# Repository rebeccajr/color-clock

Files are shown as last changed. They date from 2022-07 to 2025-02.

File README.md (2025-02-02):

# ColorClock

## Code Location

The code base is contained in the Arduino directory located at
[./sw/arduino/color-clock-driver](./sw/arduino/color-clock-driver).

## Hardware

The project was designed using an `MKR1010` Arduino board that
interfaces with a real time clock module to keep accurate time.

### Wiring Diagram

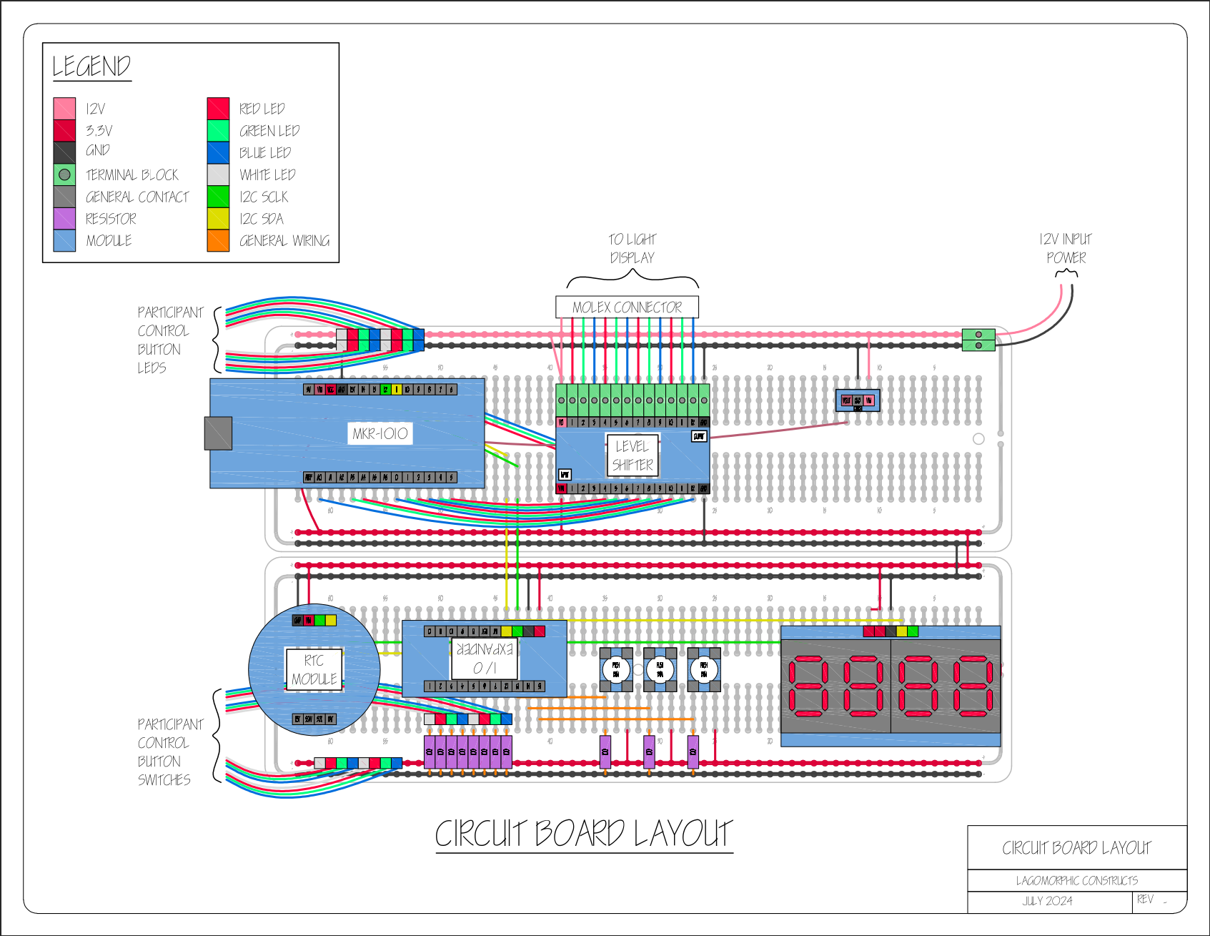
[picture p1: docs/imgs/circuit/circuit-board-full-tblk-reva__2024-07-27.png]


## Documentation

The blog about this project can be found
[here](http://rebeccarashkin.com/color-clock).

A slide deck that contains an overview of the project can be found
[here](./docs/slide-decks/2024-08-10__demo/_color-clock-demo__2024-08-10.pdf)

## Description

Version 1 of ColorClock was an art piece displayed at Burning Man in
2024. The piece was a minimalist lean-to shade structure, housing a
2.5 ft diameter light display at its core. Within, a bench invited
participants to rest just above the playa. The light display, crafted
with concentric circles, marked the current time, providing nuanced
granularity such as the hour and minute. A user-controllable central
light introduced an element of interactivity. With a control panel,
the participant could manage cycle time and spectrum hues, enhancing the
understanding of the piece. ColorClock, in its simplicity and
interactivity, prompts contemplation on the temporal interplay of light
against the expansive backdrop of the playa landscape.

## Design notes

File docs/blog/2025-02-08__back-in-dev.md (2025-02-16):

# Back In Development

I would like to make the ColorClock code base more robust, so I
decided to leverage some of the work I'm doing in my real job and
applying it to ColorClock.

## Google Test

During development of ColorClock Version 1, I did some rudimentary
unit tests that took the form of print statements in simple C++
programs. I played around with writing makefiles but my unit tests were
few and far between.

In my latest work, I'm implementing a "real" unit testing framework in
using Google Test. Each module has its own test file and I'm using
**make** to build the unit test executable.

## Testing Limitations

Since ColorClock is designed to work with specific hardware, some of the
code isn’t easily testable using Google Test. However, much (or at least
some) of the hardware-dependent functionality is protected by
preprocessor directives, providing alternate behavior for non-hardware
builds. My goal is to write unit tests for as many functions as
possible.

## This Is Why We Test

So, I’ve started writing tests for the edge cases in the TimeCalcs
module, and guess what? I found some errors in one of the functions 😅

I didn't run into these issues with ColorClock Version 1 because it was
built for a specific use case, but as I expand the project, I need to
address them 😬

*Google Test Output for TimeCalcs*

```googletest
[==========] Running 5 tests from 1 test suite.
[----------] Global test environment set-up.
[----------] 5 tests from TimeCalcsGroup
[ RUN      ] TimeCalcsGroup.TimeAsFractionalOffset_Nominal
[       OK ] TimeCalcsGroup.TimeAsFractionalOffset_Nominal (0 ms)
[ RUN      ] TimeCalcsGroup.TimeAsFractionalOffset_Nominal_Swapped
[       OK ] TimeCalcsGroup.TimeAsFractionalOffset_Nominal_Swapped (0 ms)
[ RUN      ] TimeCalcsGroup.TimeAsFractionalOffset_Across_Midnight
/home/flux/git/color-clock/sw/test/build-test/../main/test-time-calcs.cpp:69: Failure
Value of: function_output == 0.75
  Actual: false
Expected: true

[  FAILED  ] TimeCalcsGroup.TimeAsFractionalOffset_Across_Midnight (0 ms)
[ RUN      ] TimeCalcsGroup.TimeAsFractionalOffset_Midnight_As_24_End
[       OK ] TimeCalcsGroup.TimeAsFractionalOffset_Midnight_As_24_End (0 ms)
[ RUN      ] TimeCalcsGroup.TimeAsFractionalOffset_Midnight_As_0_End
/home/flux/git/color-clock/sw/test/build-test/../main/test-time-calcs.cpp:95: Failure
Value of: function_output == 0.5
  Actual: false
Expected: true

[  FAILED  ] TimeCalcsGroup.TimeAsFractionalOffset_Midnight_As_0_End (0 ms)
[----------] 5 tests from TimeCalcsGroup (0 ms total)

[----------] Global test environment tear-down
[==========] 5 tests from 1 test suite ran. (0 ms total)
[  PASSED  ] 3 tests.
[  FAILED  ] 2 tests, listed below:
[  FAILED  ] TimeCalcsGroup.TimeAsFractionalOffset_Across_Midnight
[  FAILED  ] TimeCalcsGroup.TimeAsFractionalOffset_Midnight_As_0_End

 2 FAILED TESTS
```

## Build Flags

I have a file called [flux_macros.hpp](https://github.com/rebeccajr/color-clock/blob/main/sw/arduino/color-clock-driver/flux-macros.hpp)
that defines all the build flags, including preprocessor directives for
enabling hardware-specific functionality. This file is included in every
software module. One of its macros, **DEBUG_CPP**, is meant for
non-hardware builds. Until now, I’ve had to manually set this flag in
the macros file. To streamline the process, I wrote a simple
[Python script](https://github.com/rebeccajr/color-clock/blob/main/sw/test/build-test/add-debug-macros.py) that automatically uncomments the line.

```cpp
// #define DEBUG_CPP
```

and converts it to:

```cpp
#define DEBUG_CPP
```

In the [makefile](https://github.com/rebeccajr/color-clock/blob/main/sw/test/build-test/Makefile)
for the unit tests, I create a phony target that runs the Python script
first before building out the unit test executable 😎

## File Headers

Another improvement I made to give the code a more professional look was
adding a comment header to each file. To make this process more
efficient, I wrote a Python script that automatically populates the
header in each file.

```cpp
//__________________________________________________________________
//__________________________________________________________________
//      _   __   _   _ _   _   _   _         _
// |   |_| | _  | | | V | | | | / |_/ |_| | /
// |__ | | |__| |_| |   | |_| | \ |   | | | \_
//  _  _         _ ___  _       _ ___   _                   / /
// /  | | |\ |  \   |  | / | | /   |   \                   (^^)
// \_ |_| | \| _/   |  | \ |_| \_  |  _/                   (____)o
//_________________________________________________________________
//_________________________________________________________________
//
//-----------------------------------------------------------------
// Copyright 2024, Rebecca Rashkin
// -------------------------------
// This code may be copied, redistributed, transformed, or built
// upon in any format for educational, non-commercial purposes.
//
// Please give me appropriate credit should you choose to use this
// resource. Thank you :)
//-----------------------------------------------------------------
//
//_________________________________________________________________
// //\^.^/\\   //\^.^/\\   //\^.^/\\   //\^.^/\\   //\^.^/\\   //\^
//_________________________________________________________________
```

*We named our artist collective (currently me, Bo, and our friend Cody)
'Lagomorphic Constructs.' Lagomorpha is the taxonomic order that
includes rabbits—and I love rabbits. So, naturally, I went with
'Lagomorphic Constructs' 🐰*

## Home Display

On a different note, we are also working on installing the light display
for ColorClock Version 1 in the house 🏠

I powered it up for the first time since its display at Burning Man
2024 and was thrilled to see that not only did it work, but
the time was still accurate thanks to the 'real-time clock module 🎉

The first step to converting it to a home display is to sort out the
wiring...

*For ColorClock Version 1, the light display's wiring was terminated
with a Molex connector, which connected to a wire harness. The harness
then led to a 12-way terminal block mounted on the structure, which
interfaced with the electronics box.*

The diagram above was generated using DOT, a scripting language for
creating vector images. It's another technology I use at work and have
recently started incorporating into ColorClock.

*For home display, we removed the wire harness from Version 1 and directly connected the LED strips to the terminal block, which we relocated to the back of the light display.*

## TODO

Moving forward, I have a few tasks on my to-do list that I’ll continue
chipping away at...

### Unit Tests

- Write unit tests for modules:
  - TimeCalcs
  - RgbColor
  - HsvColor
  - ColorClock
  - TimeController
  - TimeDisplay
  - TopLevel
- Fix code for failures found during unit testing
- Create a pipeline that runs all unit tests

## Documentation

- Make block diagrams of the software architecture of ColorClock using
  DOT
- Add Doxygen comments and generate documentation

## Cleanup

- Organize ColorClock classes into folders
- Clean up non-Arduino code

## Hardware

- Prototype a small harware version of the light display for testing
  purposes
- Research free PCB board layout programs

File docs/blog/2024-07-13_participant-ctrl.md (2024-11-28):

As a child, I could spend entire days engrossed in puzzles. My favorites were the Mind Benders series logic puzzles, where a set of clues were provided to determine matches with limited information, such as figuring out which child owned which pet. I found immense satisfaction in solving these problems and took comfort in the certainty that there was always one correct solution. My chosen career path reflects this passion for problem-solving. Today, the puzzles I tackle are far more complex, with numerous possible solutions, each varying in its degree of optimality.

---
## The Circuit Board

My big puzzle for the week has been how to lay out the final circuit board. There wasn't enough time to have a board printed, so I'll be wiring and soldering everything manually. For the second version of ColorClock, I would like to design a printed circuit board (PCB) to simplify the soldering effort. All integrated component boards, e.g. level shifter, Arduino board, will be attached to the board with female headers, so if a component dies for some reason it can easily be swapped out without re-soldering.

I decided to go with a board that is connected much like a solderless prototyping breadboard, where each column of holes are electrically connected. This does limit the possible orientation of the modules, but it will make the final wiring a little easier given that it can be laid out nearly exactly the same as the solderless prototype.

<>

This photo shows the underside of one of the ElectroCookie breadboards. The project will have two boards side by side to accommodate for all of the control electronics. The stand offs in the middle of the board are to raise it up off the bottom of the electronics enclosure.

<>

This diagram illustrates the layout of the board, and is mostly to scale. The groups of wires extending beyond the breadboard's borders will be routed to external electronics, such as the participant buttons, power input, and light display. Although the wires are shown overlapping the modules in the diagram, they will actually be routed underneath the modules, as the modules will be elevated using female headers.

<>

This diagram illustrates the soldering layout primarily for the wires and female headers.

---
## The Box

The control panel enclosure will house the participant-facing buttons in addition to the control electronics for the installation, i.e. the breadboard discussed earlier in this post. I was planning on modeling and 3D printing the enclosure, but now I am contemplating making it out of wood and simply printing an enclosure for the breadboard that will sit inside the box. With regards to the enclosure as a whole, there are a few mechanical factors to consider, like how it will be mounted and accessed from the outside in case of malfunction.

The participant control panel will be located beneath the light display, which is mounted on a 45-degree wooden panel. The enclosure is designed as a diagonally cut rectangular prism to position the buttons vertically for easy access.

<>

This is the initial 3D model I was planning on printing. The triangular holes in the front are for the arcade buttons that the participants can use to modify one of the LED strips. With this design, there is no way to access the enclosed electronics without unscrewing the cover from the wooden panel that it would be mounted to.

<>

The little nubs at the bottom of the box are to stabilize the stand offs used to elevate the circuit board off the bottom of the box.

---
## The Structure

My partner, Bo, has been working hard on the structure, experiencing a multitude of challenges, and has practically rebuilt the frame, piece by piece. Home Depot has become our second home 😅 I have such immense respect for his tenacity in constructing a sturdy frame to bring my vision to fruition.

<>

We each spent most of the day working on our respective parts of ColorClock. I was mostly CAD-ing in the AC while he was sweating in the garage playing with power tools.

<>

This is Bo's exasperated "I can't wait to burn this thing" look. I love him 😘

<>

Me, for scale.

---
## TODOs For This Week

- Solder circuit board
- Model circuit board enclosure
- Modify software to output lower power at night

---
LinkedIn post

As a child, I found satisfaction in solving puzzles and comfort in knowing that there was always one 'correct' solution. As an engineer, the puzzles I get to solve have many 'correct' solutions with varying degrees of optimality. My Saturday was spent figuring an 'optimal' circuit board layout for the LED art installation I've been working on. I've updated my blog with some recent ColorClock progress 🤓 #colorclockevolution

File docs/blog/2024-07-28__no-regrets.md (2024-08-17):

## Mind your parens

I was cleaning up my code of magic numbers and added a few `#define` statements for the frequency values. But after uploading the program to the board I didn't understand why the the colors on the light were not changing at the correct rate. So I added a couple serial output debug prints saw that my frequency was not set properly.

---

### Code
```cpp
// Time constants
#define SECONDS_PER_MIN   60.0
#define MINUTES_PER_HOUR  60.0
#define SECONDS_PER_HOUR  SECONDS_PER_MIN * MINUTES_PER_HOUR 

// Cycle time for ColorClock object 0
// Should equal 0.00333____
#define CC0_CYCLE_TIME_HOURS 12.0 / SECONDS_PER_HOUR

//...

Serial.print("SECONDS_PER_HOUR:     ");
Serial.println(SECONDS_PER_HOUR);
Serial.print("CC0_CYCLE_TIME_HOURS: ");
Serial.println(CC0_CYCLE_TIME_HOURS);
```

### Serial Output
I was expecting `CC0_CYCLE_TIME_HOURS` to print as `0.00333` or even `0.00`. Why was it printing 12.00??
```
CC0_CYCLE_TIME_HOURS: 12.00
SECONDS_PER_HOUR:     3600.00
```

I figured out that it had something to do with my `#define` statement. I stared at the code for way too long before deciding to do away with the `SECONDS_PER_HOUR` constant and just hard code the values directly:
```cpp
#define CC0_CYCLE_TIME_HOURS 12.0 / 3600.00
```

And this worked, so whatever. I just figured that the Arduino compiler is weird and doesn't treat preprocessor directives the same as gcc. I started writing this post to complain about the Arduino compiler, so to illustrate my point, I coded up the following simple program to compile on my desktop.

### Code
```cpp
#include <stdio.h>

#define SECONDS_PER_MIN   60.0
#define MINUTES_PER_HOUR  60.0
#define SECONDS_PER_HOUR  SECONDS_PER_MIN * MINUTES_PER_HOUR 

#define CC0_CYCLE_TIME_HOURS 12.0 / SECONDS_PER_HOUR

int main()
{
  printf("\nSECONDS_PER_HOUR:     %f", SECONDS_PER_HOUR);
  printf("\nCC0_CYCLE_TIME_HOURS: %f", CC0_CYCLE_TIME_HOURS);

  return 0;
}
```

But then to my surprise, the console output displayed the same value as the Arduino serial out!

### Console Output
```cpp
SECONDS_PER_HOUR:     3600.000000
CC0_CYCLE_TIME_HOURS: 12.000000
```

I stared at the code again and realized that the lack of parenthesis in the definition for `SECONDS_PER_HOUR` was the source of my problem. The `#define` macro is a simple find and replace, so what the compiler saw was:

```cpp
#define SECONDS_PER_MIN   60.0
#define MINUTES_PER_HOUR  60.0

// The compiler sees:
// #define SECONDS_PER_HOUR  60.0 * 60.0
#define SECONDS_PER_HOUR  SECONDS_PER_MIN * MINUTES_PER_HOUR 

// The compiler sees:
// #define CC0_CYCLE_TIME_HOURS 12.0 / 60.0 * 60.0
#define CC0_CYCLE_TIME_HOURS 12.0 / SECONDS_PER_HOUR
```

The compiler was basically seeing 12 / 60 * 60 instead of 12 / (60 * 60). And because of order of operations, `CC0_CYCLE_TIME_HOURS` was indeed 12, not the 0.003333 that I was hoping for 🤦‍♀️

---

## We did it live!

A couple months ago we decided to schedule a live demo as motivation to get the project finished a few weeks before leaving. The looming date of the demo gave us the motivation to finish with exactly one weekend to spare to get ready 😵‍💫

Last weekend was the demo and it was a success! I started out the event with a presentation where I discussed some of concepts of RGB LEDs, how a level shifter works, and went over the wiring of the circuit board. After scrambling to get it all wired up (which involved an embarrassing number of aligator clips) I threw together the slide deck and was excited to feel like a teacher again.

*Here is the final wiring of the circuit board. Isn't it beautiful?* 🥰

---
## No regrets

For a long time, I regretting getting my bachelor's in electrical rather than computer engineering. Often enough I have questions about software engineering design concepts that might have been answered had I chosen a different major. However, while working on ColorClock I realize that my degree gave me familiarity with electronic components and datasheets that I might not have gotten with a different undergraduate focus. And for the first time since I graduated, I sincerely have no regrets about my choice.

A lot has happened since the last post, including completely resoldering a new circuit board followed by a very sad afternoon where I was ready to give up after burning *another* Arduino board. But Bo came to the rescue and discovered that it was just a grounding problem.

---
# The final touches

This is our last weekend before we deliver and I'm thrilled that we are really just putting on the final touches. Although I learned today that last minute software changes can be quite risky.

[](https://youtu.be/9BzPTI5HZrY)
*I decided to change the initial colors for the the participant controlled central light, but because of the wonky logic for how the buttons interact with the colors, I got less ideal results.*

https://youtu.be/CMCiZth6IXw
*I reverted my software change and now it's working* 🥳

---

This weekend I'm finally at the point that I wanted to be *last* weekend. After spending almost all of last Saturday soldering I learned that powering the Arduino with 12 volts no bueno 😵 But I knew I had some LM7805s (5 volt linear regulators) somewhere. Then a series of unfortunate events ensued...

- Soldered it too close to where the Arduino was supposed to go
- Battled with desoldering, surrendered the part
- Soldered in a new voltage regulator
- Realized I soldered it in backward
- Added new wires to make it work
- Plugged in the wrong Arduino board because it had the same footprint
- Realized level shifter wasn't working
- Battled with desoldering the headers from the component
- Gave up and soldered on longer pins
- Wired everything and found the on board buttons weren't working when the lights were on
- Fried my Arduino board while debugging

```cpp
#define SECONDS_PER_MIN   60.0
#define MINUTES_PER_HOUR  60.0
#define SECONDS_PER_HOUR  SECONDS_PER_MIN * MINUTES_PER_HOUR 
#define CC0_CYCLE_TIME_HOURS 12.0 / SECONDS_PER_HOUR
//...
Serial.print("CC0_CYCLE_TIME_HOURS: ");
Serial.println(CC0_CYCLE_TIME_HOURS);
Serial.print("SECONDS_PER_HOUR:     ");
Serial.println(SECONDS_PER_HOUR);
```
Output
```
CC0_CYCLE_TIME_HOURS: 12.00
SECONDS_PER_HOUR:     3600.00
```

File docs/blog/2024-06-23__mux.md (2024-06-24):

## Another Futile Effort
It looks like using a multiplexer as a PWM expander is not going to work. As previously discussed, in order to wire up three RGB LED strips to change colors at different frequencies, ill there is need for 12 analog output pins, one each for red, green and blue on each of the RGB LED strips. For the Arduino that we have selected, this will completely max out the number of analog output pins I have.

A couple months ago I tried to use a constant current I/O expander to write to PWM pins, but my tests did not yield favorable results. I did some googling and found that some developers will use a multiplexer as a way to increase the number of I/O pins to write to (or read from). I found the CD74HC4067 part, which is a 16-1 mux (with 4 control signals) which would provide ample outputs for the number of analog signals required by ColorClock.

## Back to Computer Engineering 101
To review some digital logic, a multiplexer is basically a switch that can select from many inputs. When I used to teach, I compared it to a vending machine. There are many inputs (e.g. chips, granola, gum, candy) and one output (your selection). We type in a code on the keypad to select what kind of snack we want.

<>
The snacks are the selection of inputs and the dispensing slot is the output. The keypad acts as the set of control signals used to select which input should be connected to the output.

## Mux for PWM Output? Wishful Thinking 🥺

We can flip this diagram 180 and instead of having many inputs to one output, we can have one input to many outputs. If we change the selection fast enough, we can write to all of the outputs (allegedly) virtually simultaneously.

<>

The idea here is to have one common signal pin (with the PWM value) that can write to one of many outputs (RGB LED terminals). You can switch the control lines to change the output, i.e. channel, of the mux and do an analogWrite for each channel.

So we can write the PWM value for a red pin, change the channel, write to the green pin, change the channel, write to the blue output, etc. My thought was because our eye's persistence of vision, we wouldn't be able to detect any flickering.

Buuuuuuut... that wasn't the case 😑 My tests showed significant flicker (even only writing to two channels) and the colors just didn't display properly. The videos below show the results of my tests.

## Testing Results
In all of the tests described below, I am trying to display magenta on my RGB LED:

```cpp
void setup()
{
    //____________________________________________
    // Common pin that all values are written to
    //____________________________________________
    pinMode(common_pin, OUTPUT);

    //____________________________________________
    // Display the color magenta,
    // i.e. max values for red and blue, no green
    //____________________________________________
    color = RgbColor(0xFF00FF);
    //____________________________________________
}
```

## Test 1: Perform analogWrite and Channel Select Sequentially
```cpp
void loop()
{
    //____________________________________________
    // NOTES:
    // 1) `Rgb::RED`, `Rgb::GRN`, `Rgb::BLU`
    //    are values from an enumeration
    // 2) muxxy is the multiplexer object
    //____________________________________________
    analogWrite(common_pin, color.rgb_[Rgb::RED]);
    muxxy.channel(0);
    analogWrite(common_pin, color.rgb_[Rgb::GRN]);
    muxxy.channel(1);
    analogWrite(common_pin, color.rgb_[Rgb::BLU]);
    muxxy.channel(2);
}
```

The light should be displaying a magenta color, i.e. equal voltage on the red and blue pins, and no voltage on the green pin. Instead, the light looks white, which equates to equal voltage on each of the red, green and blue pins.

## Test 2: Set Channel Before analogWrite
```cpp
    muxxy.channel(0);
    analogWrite(common_pin, color.rgb_[Rgb::RED]);
    muxxy.channel(1);
    analogWrite(common_pin, color.rgb_[Rgb::GRN]);
    muxxy.channel(2);
    analogWrite(common_pin, color.rgb_[Rgb::BLU]);
```

There is no significant different between selecting the channel before the analog write.

## Test 3: Only Write to Red Channel
```cpp
    muxxy.channel(0);
    analogWrite(common_pin, color.rgb_[Rgb::RED]);
```

<>

Only writing to one channel displays the color properly. This test was performed just to ensure it was actually writing the value.

## Test 4: Only Write to Red and Green Channels
```cpp
    muxxy.channel(0);
    analogWrite(common_pin, color.rgb_[Rgb::RED]);
    muxxy.channel(1);
    analogWrite(common_pin, color.rgb_[Rgb::GRN]);

    Debug::print_labeled_int("green val: ", color.rgb_[Rgb::GRN]);
```

<>

There is no green in magenta, so this test *should* only display red on the LED. Instead, we are seeing green flickering, and not any red at all. I also output a serial print for the value of green to ensure that green was indeed set to zero, and this was true.

## Test 5: Reset Output to 0
```cpp
    muxxy.channel(0);
    analogWrite(common_pin, color.rgb_[Rgb::RED]);
    analogWrite(common_pin, 0);
    muxxy.channel(1);
    analogWrite(common_pin, color.rgb_[Rgb::GRN]);
    analogWrite(common_pin, 0);
```

<>

Resetting the output pin to zero before switching channels just makes it look more choppy. Green is still displayed, though it shouldn't be.

---

## We Can't Have Everything
So... I'm sticking to the PWM (analog) out pins from the Arduino for now. I *also* wanted to have a variable output for the light-up arcade buttons on the participant control panel so the brightness of the buttons would change as a result of particpant interaction. I won't be able to do this because I have no free analog output pins 😒

In addition to the outputs for the light display, I also need digital input pins from the participant and programmer control panels (the programmer control panel will be hidden from the audience and is used for time set control). So I will proceed to test the previous I/O expander I used (Adafruit AW9523) for digital input and hope it works for this purpose.

## Hindsight is 20/20
In retrospect, I really should have just selected individually addressable LED strips for the light display. This would have eliminated all need for analog output because I would have been able to control the lights with a simple I2C line. But the code was already written assuming PWM outputs, and I didn't want to write another interfacing layer. But with all the extra code I've had to write to test these additional modules, the interface layer to I2C would have been trivial.

But... we're here now. Initially, I was only anticipating one LED strip, a clock that would cycle over 24 hours, so I would have only needed three PWM pins for the light display. But scope creep happened (for good reason, this design is way more interesting) and now we have four LED strips, all cycling through the spectrum at different frequencies.

# There's One Win...
In other good news, I wrote the code to modify colors based on participant input, so yay!

Alright... now I'm back to testing the original I/O expander, this time to take digital input 😵‍💫

---
LinkedIn

I feel like most of engineering is figuring out what not to do, like trying to use a mux as a PWM I/O expander in my ColorClock art installation 😬 My thought was that our eyes' persistence of vision would make any flickering undetectable, but a flickering output was the least of the issues. I'll still need an I/O expander for the participant control panel, so I'll be back to testing the Adafruit AW9523. Hopefully I have better luck with digital reads than I did with analog writes...

6 weeks and counting 😅

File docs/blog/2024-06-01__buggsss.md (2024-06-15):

## IO Expander Analog Write Fails Me

Although the code for the IO expander compiles successfully, it doesn't produce the expected variable output voltage. The analogWrite function accepts values from 0 to 255 (0xFF) and normally setting it to 128 would result in half the output voltage compared to setting it to 255. However, I discovered that the output voltage remained the same whether the pin was set to 128 or 255.

In a previous test, I connected an LED and cycled through output values from 0 to 255, observing the LED brightening. But the differences in output voltage didn't scale as anticipated; there might be a variation up to a certain point, beyond which the voltage levels off.

```cpp
// pin_num0 and pin_num1 produce the same output voltage
analogWrite(pin_num0, 128);
analogWrite(pin_num1, 255);
```

The `digitalWrite` function still works but I haven't the `digitalRead` yet. If `digitalRead` works, we *might* use this IO expander for the user control panel input buttons. But my confidence level in this piece of hardware is low, so we'll see if I actually end up using it.

Now I'm back to using ALL the Arduino PWM output pins to wire up the four LED strips. I'm a bit apprehensive about maxing out the available analog output pins, so I've ordered a new multiplexer, the CD74HC4067, as a backup solution for expanding analog outputs. The new parts have arrived, so I'll be soldering and testing them this weekend... 🤞

<>

*The new multiplexor. I'll need to solder on the headers prior to testing.*

## 12V Level Shifter Works!
In this project, an Arduino output pin provides up to 3.3V, insufficient for the 12V needed by the RGB LED strips. So we're using a level shifter to boost the voltage to 12V.

In recent testing, I connected the Arduino's analog output to the level shifter input and the RGB strip to its output, and... it was a success! 🥳 The light cycled through colors as programmed, though transitions were slightly choppy, a topic I'll address later in this post.

<>

*The level shifter input pins are connected to the Arduino analog output pins and the level shifter output pins are connected to the RGB LED strips.*

## Lesson Learned: Don't Use a Member Variable to Define a Global
After successfully testing the level shifter, I quickly integrated the three additional ColorClock objects into the code, assigning analog output pins for each new strip. However, upon connecting more LED strips and running the code, the board appeared to freeze. Subsequent attempts to upload new code failed as the computer no longer detected the Arduino's serial port. Resetting the board and reseating the USB cable eventually restored the serial port connection. Despite this, re-uploading the program continued to cause the board to freeze again 😵‍💫

I barely touched the code! I was worried there was something on the board shorting so it took me about a day of swapping out hardware, doing incremental testing, and meticulously comparing Git commits before I identified the problem.

In the last commit where everything broke, I made one tiny optimization in an effort to reduce the use of 'magic numbers'... In the definition of the time periods for each color clock, I used a static member variable, `TimeCalcs::SEC_IN_HR`.

```cpp
float cc0_period =  6.0 / TimeCalcs::SEC_IN_HR;
float cc1_period = 12.0 / TimeCalcs::SEC_IN_HR;
float cc2_period = 30.0 / TimeCalcs::SEC_IN_HR;
float cc3_period = 60.0 / TimeCalcs::SEC_IN_HR;
```

I should note that the three `cc#_period` variables used are globals in the main driver file. It seemed like the driver file was not aware of the value of `TimeCalcs::SEC_IN_HR` by the time it ran that part of the code. When I removed this reference to `TimeCalcs::SEC_IN_HR` it worked again 😅

```
float cc0_period =  6.0 / 3600.0;
float cc1_period = 12.0 / 3600.0;
float cc2_period = 30.0 / 3600.0;
float cc3_period = 60.0 / 3600.0;
```

I'll probably create some `#define`s at the top of the file to keep it looking a little cleaner.

## Smooth Transitions

At first, I thought updating the color output every second would be enough since our original design had a 24-hour cycle time. But once we added a user-controlled light that allows participants to set cycle times as short as six seconds, I realized that smoother color transitions were essential for seamless aesthetics.

I am using a real-time clock module to output the current time, which the program uses to determine the color and the module's smallest granularity is one second. However, Arduino has a built-in function that outputs the current number of milliseconds since the program started, so I added a function to output the current millisecond within each second.

```cpp
int FluxClock::get_milli(byte crnt_sec)
{
  static byte prev_sec = 0;
  static long int prev_millis = 0;
         long int crnt_millis = millis();

  // Resent millisecond count if its a new second
  if (crnt_sec != prev_sec)
  {
    prev_sec = crnt_sec;
    prev_millis = crnt_millis;
  }

  return static_cast<int>(crnt_millis - prev_millis);
}
```

The two videos included below demonstate the differences when updating the color output every second versus every millisecond. The three RGB LED strips in the videos cycle through all hues in the color wheel at different rates: 6 seconds, 12 seconds, and 30 seconds.

🌈

*In this implementation, the program is updating the color output every second. Notice how abrupt the color transitions appear.*

<>
*Here, the colors are updated every millisecond. The transitions in this implementation are much smoother than before.*

## OS Reinstallation is Always an Option
In the period of time that I started writing this post, I experienced an issue where the Ubuntu partition on my desktop decided not to connect to the internet. I struggled for a few days with all sorts of network settings before I realized it wasn't worth the trouble and just reinstalled Ubuntu in its entirety. As I was going through my whole new environment setup process, I [documented](https://github.com/rebeccajr/setup-files/blob/main/new-environment-setup.md) most of what I did to streamline the next time I have to start over 😅

## User Interface Software Design Begins!

The next step in the ColorClock saga is to design the software implementation for the participant-facing user control panel. I wired up a little prototype for testing. The final design will use arcade buttons embedded in an enclosure that will house the electronics.

<>

In this small prototype I'm using breadboard-sized push buttons and LEDs. The final control panel will use light up triangular arcade buttons for red, green, blue, and frequency modification. I'm using one current-limiting resistor for all the LEDs and 10K pull-down resistors for each push-button.

<>

The soldering work is not beautiful but it gets the job done.

---
LinkedIn

The MVP version of ColorClock software is working! 🎉 Next on the agenda: designing the state machine for the participant-facing user control interface. We're getting there...

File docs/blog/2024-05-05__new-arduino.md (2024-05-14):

# The mystery of the missing package
sA couple weeks ago I was tearing my house apart to find a package from Adafruit that I remember arriving a couple months prior. I'm not one to put something in a random place (an ongoing challenge I'm actively addressing!), so it turned into a whole week of organizing and repeatedly checking all the logical places it could be. I felt like I was going crazy.

I finally decided to find the email delivery confirmation but it was non existent in my inbox. And then I went to the Adafruit website and found a shopping cart containing all the items I was expecting in my package 😑 Looking at my shopping cart of unpurchased items, the real memory of what happened came flooding back... I was shopping for an encoder but couldn't commit and probably went to bed with intentions of finishing my shopping the next day but life got in the way. Studying my shopping cart, I discovered that one of the items I had planned to purchase was no longer in stock 😫

Lessons learned:
1. When having trouble finding a mailed package, first check if the items were ever ordered.
2. Don't put off ordering a shopping cart full of items in hopes of finding that last perfect addition.

# A new Arduino
One of the other items I had ordered that week was a new, smaller Arduino board. I have been using this old board I acquired from my brother years earlier that he was never able to connect to (it turns out he was using a power cable instead of a data cable to program 😅). For the final ColorClock installation, I want to make two identical circuit boards so I have a backup in case there are any problems during the week the project is being displayed.

I ordered an Arduino Nano ESP32 where nearly all of the pins are configurable to have PWM, a way to fake out an analog output with a digital signal. PWM output is what I need to have variable output voltage so I can send different outputs to the RGB LED pins creating different colors.

# Nothing good is ever easy
So, I had this new Arduino and I just wanted to do a simple test so that I know I can program my new Arduino. In my last post I shared my frustration with figuring out how to set build variables so I went back to developing on my beloved decade-old MacBook Pro. But after I figured out how to set build variables I migrated back to my new fancy Windows machine and applied the same changes to the `boards.txt` deep in the file system in the Arudino hardware folder. At that point I continued development on Windows.

Ok, so back to the new Arduino board... I installed the drivers to talk to this board but I kept getting errors when trying to program it:

```
dfu-util: Cannot open DFU device 2341:0070 found on devnum 10 (LIBUSB_ERROR_ACCESS)
dfu-util: No DFU capable USB device available
Failed uploading: uploading error: exit status 74
```

I discovered that this was a known problem with this board and found in the Arduino forums that there is a [`post_install.sh`](https://arduino.github.io/arduino-cli/0.35/platform-specification/#post-install-script) script I need to run for the computer for computer to see the Arduino. But this was a Bash script, and I was developing on Windows. I tried running the command in Git Bash, but I needed to use `sudo` and Git Bash didn't have `sudo` then I tried to run it in PowerShell just for fun.

## A side note
Skipping ahead to the present, as I'm cleaning up this post and adding links, I have discovered that there is indeed a `post_install.bat` script that I probably could have run on Windows, but we're here now.

# A solution to my development woes
The time had come to create a Linux partition. I was experiencing the same level of fear I had about `arduino-cli`, the command line tool for building and uploading Arduino code. Creating a Linux partition seemed scary because I had never done it before. But dammit I am a software engineer and I can do hard things!

My supportive partner assured me that installing a Linux partition was not complicated. All I needed to do was download the Linux installer, put it on a USB drive, make it bootable, then boot into that USB drive. *deep breath* I can do this.

Creating a bootable USB was surprisingly painless. There are tons of instructions on the internet. The basic steps were:
1. Download the Linux installer image.
1. Make the USB stick bootable.
1. Restart the computer and enter the BIOS.
1. Select the USB from the boot menu.
1. Follow on-screen instructions.

So I did it! I am actually writing this from my Ubuntu partition right now!

Like any new computer, there's the initial setup process, which, in my case, was missing even basic tools like Vim. But I'm no stranger to starting over.

# Back to the new Arduino
The catalyst for the Linux partition was so that I could run a script that would allow my computer to see the Arudino Nano ESP32. I did all the things (installed `arduino-cli`, ran the `post_install.sh` script) and it's all working!

My next challenge is to test my new RTC module, test the I/O expander 🥺 (also scary) and start laying out the 'final' V1 version of the circuit board.

# It's official
I almost forgot to report some other fantastic news! ColorClock is officially listed as 2024 Playa Art!!

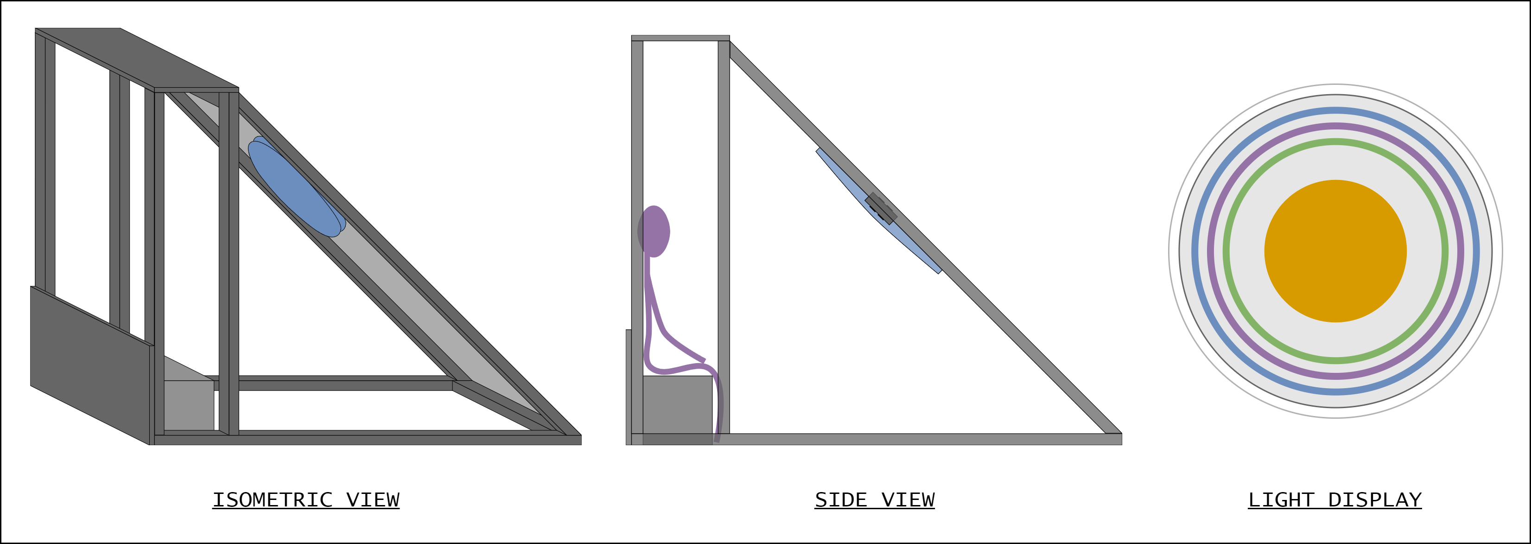
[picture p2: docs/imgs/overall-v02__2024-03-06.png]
overall diagram of colorclock (https://burningman.org/event/2024-art-installations/?yyyy=&aq=colorclock&support_project=0)


---
LinkedIn summary

I'm thrilled to announce a new update on ColorClock's progress! Facing challenges with Arduino programming on Windows, I took a significant step forward by creating a Linux partition to reduce the development struggle. Check out my blog to stay in the loop.

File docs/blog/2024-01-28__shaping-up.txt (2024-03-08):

ColorClock Design is Shaping Up
It's been a productive weekend for ColorClock design. My collaborator / partner and I have decided on a form that we are happy with and are now looking into materials - and consequently design modifications to accommodate for standard sizing and availability of said materials.

Fabrication
Up until this point, the physical design of ColorClock has been undefined; I've focused on the software and less on the construction of the end product. I've been drawn to the idea of a circular light which is in line with the cyclical nature of time, and the form factor of a wall clock. We considered that this piece needs to be visible during the daytime in a sunny desert, so the light needs to be shaded in some way. After countless discussions, we were thrilled to settle on this simple lean-to type shade structure with the light visible from underneath. We also decided to include a bench under the structure so that viewers would be able to experience a reprieve from the sun while enjoying the view of the ColorClock.

Hardware
The current design of ColorClock calls for non-addressable RGB LEDs, since the light only needs to display one color at any given time. We are considering either constructing our own light fixture with RGB LED strips, individual LEDs, or using a pre-fabricated circular PCB with a LED matrix. As of yesterday morning, we were leaning more towards using a pre-fabricated board to reduce the complexity of assembly and it will probably just be prettier than something we make ourselves. But when considering the size of the light that we would like (~3 foot radius), buying something pre-fab might not be feasible. There's also the question of whether we want to use RGB LED strips, or to use individual LEDs, and embark on the challenge of soldering ~200 LEDs by hand 😅

Software
The bulk of the software design and architecture is complete; the time-to-color algorithm is working, and the gradual change from one color to the next is also functioning properly. I paused development in 2021 when my test circuit was not smoothly transitioning from one color to the next but we figured out that I was simply using the wrong output pins of the Arduino. The next software task is to take user input in the form of switches to allow the time to be set externally.

The current software design uses the assumption that the LEDs are non-addressable. The time-to-color algorithm outputs three values, red, green, and blue. But if I end up using addressable LEDs, I will have to add another layer of architecture to take the RGB values and send them to the board. I'll cross that bridge when/if I get there.

Though it's possible my LED programming design will have to be modified, for now I'm directing my attention to debounce logic for pushbutton input 🤓

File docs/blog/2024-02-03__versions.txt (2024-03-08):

An Iterative Approach
I have decided on a multi-stage approach to development where each iteration has increased functionality to the previous. This diagram illustrates the top-level electronic design, with each iteration of implementation.

Top-Level Schematic

Notes
RGB PWM wires represent the red, green, and blue PWM outputs from the Arduino. The output from the Arduino will be stepped up to 12V to power the LEDs on the light display.

I2C serial wires include clock (SCL) and data (SDA) lines.

Time display is used by the artist during installation. Time display will be hidden from viewers.

Version Summary
V0 	| 	Minimum viable product; one ColorClock with 24 hr cycle time

V1 	| 	Includes interface and second ColorClock for participant interaction

V2 	| 	Includes additional ColorClock to previous versions with 60 min cycle time

V3 	| 	Includes additional ColorClock to previous versions with cycle time equivalent to length of event week

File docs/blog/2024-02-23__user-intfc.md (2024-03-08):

Navigating Vision vs Feasibility
This week I've been navigating the balance between my artistic vision and feasibility of execution for the user interface of the piece. I've also been working on the software development involved in accepting user input through button presses.

Software Development
Recent software development efforts have been focused on button logic. The control panel interface will have two purposes:

Time set control (should only need to be used once)

User interface control

I created a class for a momentary switch with a state machine to determine the kind of input it might receive by the user, e.g. short press, long press, double press. And of course before it enters the state machine I added a function to debounce the input so that the electronics would not register multiple button presses even though the user intended to only press the button once.

In the last few days I've realized that I will need to have different kinds of MomentarySwitch classes to register different types of button presses. For instance, the MomentarySwitch class I designed will not register a press and hold for the purpose of incrementing a value multiple times. For example, if we want to set our oven timer to 90 minutes, we shouldn't have to press the increase time button 90x. We know that we can hold the button then it will start to increment first by 1 minute, then 10.

So I will likely have a base class of MomentarySwitch with a set of states (IDLE, PRESS, RELEASE, WAIT) and several sub classes that will handle states differently.

User Interface Design
All this button pressing talk has also gotten me thinking a lot about what the user input would actually look like. To recap, the light fixture design entails two or three outer rings of light reflecting the current time, complemented by a central light in the middle, providing users with interactive capabilities.

Light Display: Outer rings of color light traverse through the spectrum at different rates, representing different granularity of time. The central light can be controlled by participants.

A straightforward user input option involves a basic knob (involving an additional software design effort) to control the cycle time of the central light. However, I'd also like to offer participants a way to influence the color as well.

The user interface should be simple, clean, and intuitive. I was initially really attached to the minimalist design illustrated in Version 1. There would be a knob on the left that would control the cycle time and a set of increment decrement buttons to control... something. Alternatively, the up and down buttons could cycle through a set of pre-defined color schemes. But with pre-defined color schemes, there would really be no reason to have the buttons represent increment or decrement.

Version 1: The initial concept for participant interaction with light display. A knob selects cycle time and two triangular buttons control an aspect of visual effect. This design was discarded due to limitations in user control while maintaining intuitive design.

I started to wonder, "What aspect of color could the user feasible control with only an increment and decrement button?" I could program some logic that involves pressing multiple buttons at once. But then the control wouldn't be intuitive. So I came up with the design in Version 2 where the middle switch is an RGB LED 3-way rocker which would serve as an RGB color select. The user would select which aspect of the color they want to change for the spectrum, then they would increment or decrement the overall values of red, green, or blue.

Version 2: Left-most switch is a knob to control cycle time as indicated in Version 1. The middle switch is a 3-way rocker for color selection. Triangular buttons increment or decrement color selected by rocker switch. Either rocker or triangular buttons illuminate in red, green, or blue, reflecting user selection.

I knew that there was a slim chance that an RGB LED rocker switch would exist without having to make one myself. So then I decided that the increment and decrement buttons could be RGB and that they would reflect the color selected from the rocker switch. How hard can it be to find RGB LED triangular arcade buttons? Well, it turns out that I can't really find these either.

My quest for RGB LED arcade buttons revealed only round options. For aesthetic purposes, it is important to me that there be shape differentiation between the switches for cycle time control and color select. And I'm pretty attached to triangles for increment and decrement. So, I've come up with the design in Version 3 where I'm now using a round RGB LED button for color select and a slider for cycle time.

Version 3: The left-most switch is a slider used to control the cycle time, the center button will illuminate as either red, green or blue, and the right set of triangular switches will be white or grey.

The control panel design will likely continue to evolve as I search for slider switches that align with my vision, but for now I need to put some of these buttons on order. And in the mean time I need to expand my software to account for new switch input behavior.

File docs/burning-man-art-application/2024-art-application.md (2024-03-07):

# Description
This file contains the art registration questionaire for a Burning Man art piece.

# RIDE
ColorClock aligns with the values of Radical Inclusion, Diversity, and Equity (R.I.D.E.) by integrating a user-friendly interface transcends technical barriers. The user interface of ColorClock is intentionally designed to be simple and intuitive, ensuring accessibility for participants with varying levels of technical knowledge. This deliberate simplicity extends beyond technical accessibility; as ColorClock represents time without traditional numbers, it becomes an invaluable tool for those who may face challenges processing conventional time information.

# Roles and Skills on Playa
Supervisor & LNT Lead (Rebecca): Oversees and directs installation and deinstallation, ensuring strict adherence to Leave No Trace (LNT) principles. Maintains vigilant oversight, proactively identifying and rectifying MOOP issues like loose nails.

Construction Lead (Gary): Manages tasks, overseeing precise assembly using tools (hammers, nails, screwdrivers, drills) for optimal completion.

Assistant Constructor (Cody): Supports the Construction Lead, ensuring efficient and accurate manual processes.

Electronics Lead (Rebecca): Assembles and maintains electronic components, ensuring seamless functionality and integration.

Electronics Assistant (Gary): Aids the Electronics Lead, focusing on wiring solar panels.

Rigging Team (Cody and Gary):
Manages rigging, anchoring the installation to the Playa for stability and safety.

Efficient execution with attention to quality, functionality, safety, and precise LNT practices.

# Physical Description
The ColorClock is a minimalist lean-to shade structure featuring a 2.5 ft diameter light display at its center. Inside, a short bench allows participants to sit just above the playa surface. The light display consists of concentric circles delineating the current time, offering varying granularity (e.g., hour, minute). A central light, user-controllable, add interactivity. The structure incorporates an uncomplicated, intuitive control panel enabling users to manage cycle time and spectrum hues efficiently.

# Philosophy
ColorClock defies conventional time quantification. At Burning Man, where many seek liberation from the constraints of order and time in the default world, this piece instigates reflection. By using color variation instead of numeric precision, ColorClock underscores the imprecise nature of time, emphasizing our imperfect reality. My objective is to convey a profound message about embracing temporal fluidity and acknowledging inherent limitations in our perceptions. This installation invites participants to a contemplative exploration, fostering a connection with the unmeasured essence of existence.

# Public Description
ColorClock stands as a minimalist lean-to shade structure, housing a 2.5 ft diameter light display at its core. Within, a low bench invites participants to rest just above the playa. The light display, crafted with concentric circles, marks the current time, providing nuanced granularity such as the hour and minute. A user-controllable central light introduces an element of interactivity. With an intuitive control panel, the participant can manage cycle time and spectrum hues, enhancing the understanding of the piece. ColorClock, in its simplicity and interactivity, prompts contemplation on the temporal interplay of light against the expansive backdrop of the playa landscape.

# Safety
ColorClock prioritizes occupant safety with a 'no climbing' sign, sanded edges to prevent splinters, and meticulously terminated and grounded electronics, eliminating exposed wires. No specific staffing is designated during the event, relying on these safety features and participant awareness for a secure experience.

# Installation plan

Team will perform tasks simultaneously, e.g. electronics assembly during structure assembly. No heavy machinery necessary.

Abbrev:
Artist / Supervisor (S)
Contruction Team (CT)
Contruction Lead (L)
Contruction Assistant (A)

1
CT: Unload/arrange materials
S: Level area as needed, identify the orientation in relation to the sun

2
CT: Frame assembly
S: Light display / ctrl assembly & testing, integrate light / ctrls into the shade panel

3
CT: Attach shade panels to frame
S: Intermediate MOOP sweep / inspection

5
CT: Secure solar panels
S: Place solar wiring & battery

6
L: Connect solar wiring
A: Rig structure to playa
S: Place 'no climbing' sign

7
CA: Confirm sign placement
CL: Verify electronics termination / grounding
A: Verify rigging

8
A: Initialize light display & ctrls
CT: Clean up tools / materials

9
CL: Verify light functionality, pwr generation
CA: Capture images and details for reference / future improvements
A: Rake & scan for MOOP, pack for disposal

# Lighting Plan
In addition to the light of the LED art itself, there will be solar lawn lights staked into the ground at all four corners and two more along the two shorter edges of the art perimeter, where it won't create a trip hazard for participants. If construction is performed at night, we will use these same solar lights in addition to rope lights to outline our area of work.

# Aesthetic Light Components

The heart of the piece is the 2.5 foot diameter circular ColorClock light display, RGB LEDs. It will be visible through the open side of the lean-to shade structure

# Placement
9:00 side, inner playa

# Deinstallation

We plan to disassemble on Sunday afternoon before the temple burn in the following steps:

1. Deploy expansive tarps strategically surrounding and positioned beneath the installation to capture any potential MOOP during disassembly. Place an additional tarp where disassembled materials will be gathered.

2. Disconnect and remove solar lights, and detach the light display from the shade panel.

3. Remove solar panels and deconstruct the bench.

4. Uninstall shade panels, collecting fasteners systematically.

5. Disassemble the frame, ensuring the organized collection of all fasteners.

6. Diligently fold all tarps laid out in step one, taking care to retain any collected MOOP, if present, ensuring a meticulous cleanup.

7. Conduct a thorough linear sweep of the art area with three team members, scrutinizing the Playa meticulously for any MOOP (Matter Out of Place) left behind.

#LNT plan

To mitigate potential MOOP issues during both installation and deinstallation, our strategy involves proactive measures to safeguard the playa surface. Large tarps will be strategically positioned under the installation to capture any debris, and additional tarps will be laid where materials are assembled and disassembled, ensuring a clean and organized workspace.

Recognizing that wood fasteners pose a significant MOOP concern, we will meticulously organize and count them during both assembly and disassembly. Prior to Playa installation, all wood components will undergo sanding to minimize the risk of wood shards becoming MOOP.

In adherence to Leave No Trace principles, our post-deinstallation cleanup plan includes raking the area surrounding the art piece to restore the playa to its original condition. This comprehensive approach aligns with our commitment to environmental responsibility throughout the entire project lifecycle.

# After Event
We will reuse the frame and wood panels for future art. The light display will be used as an art piece in the house.

# Modifications
The light display will be disassembled from the shade structure. We will also change the the wiring so it can be powered from a wall outlet.

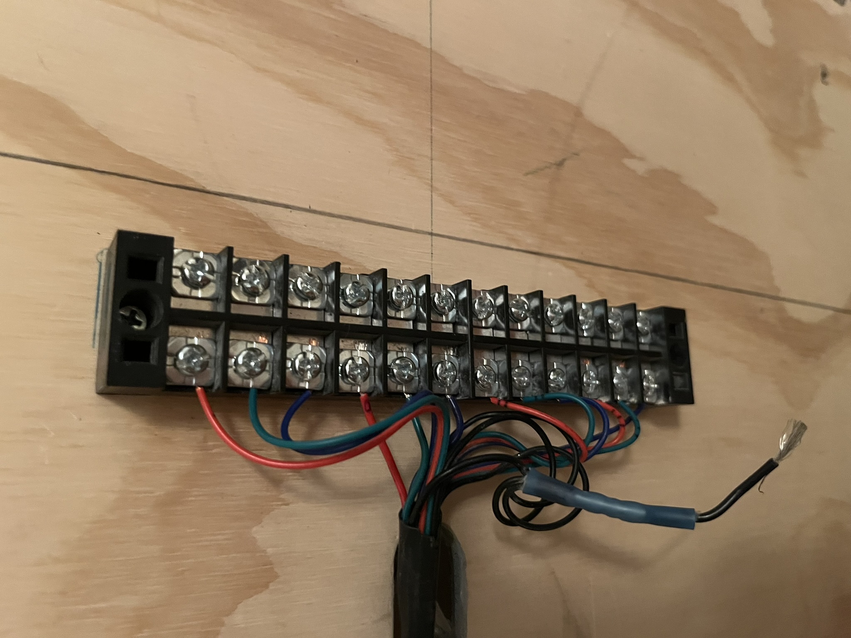
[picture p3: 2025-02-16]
docs/imgs/photos/hardware/terminal-block-wall-mout__2025-02-08.JPEG

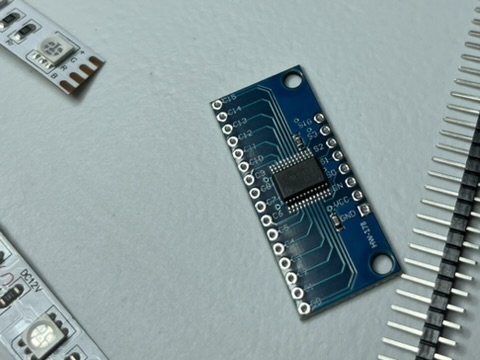
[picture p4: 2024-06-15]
docs/imgs/photos/hardware/mutiplexor__2024-06-15.JPEG

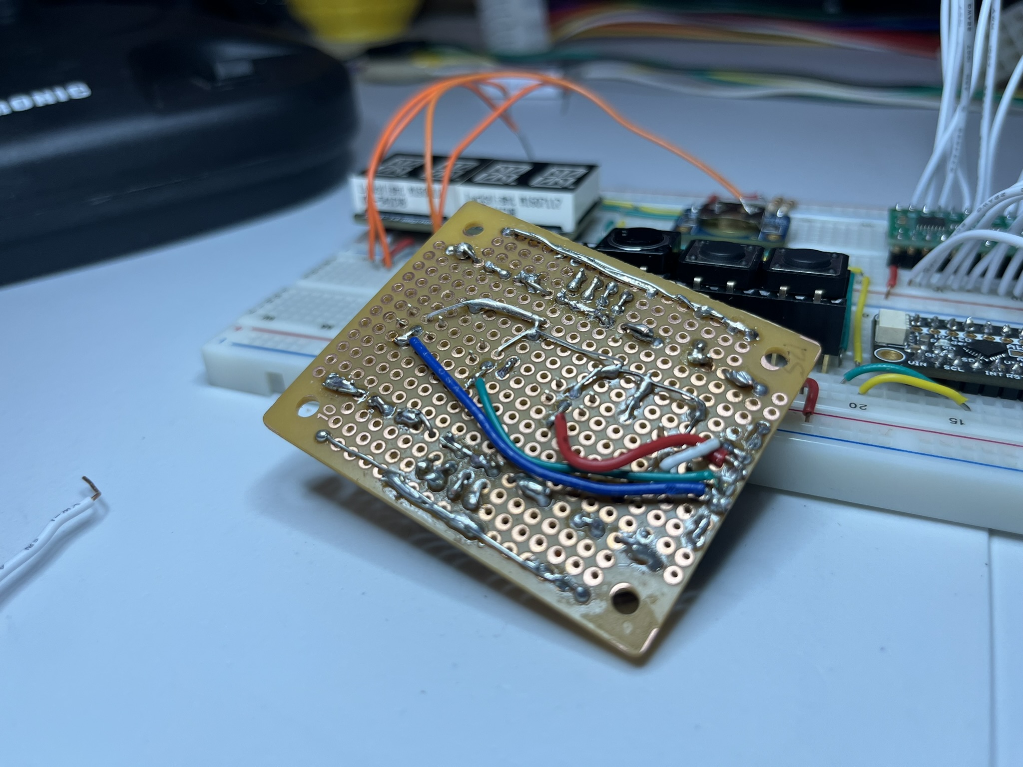
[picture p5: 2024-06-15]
docs/imgs/photos/hardware/user-control-prototype-back__2024-05-31.JPEG

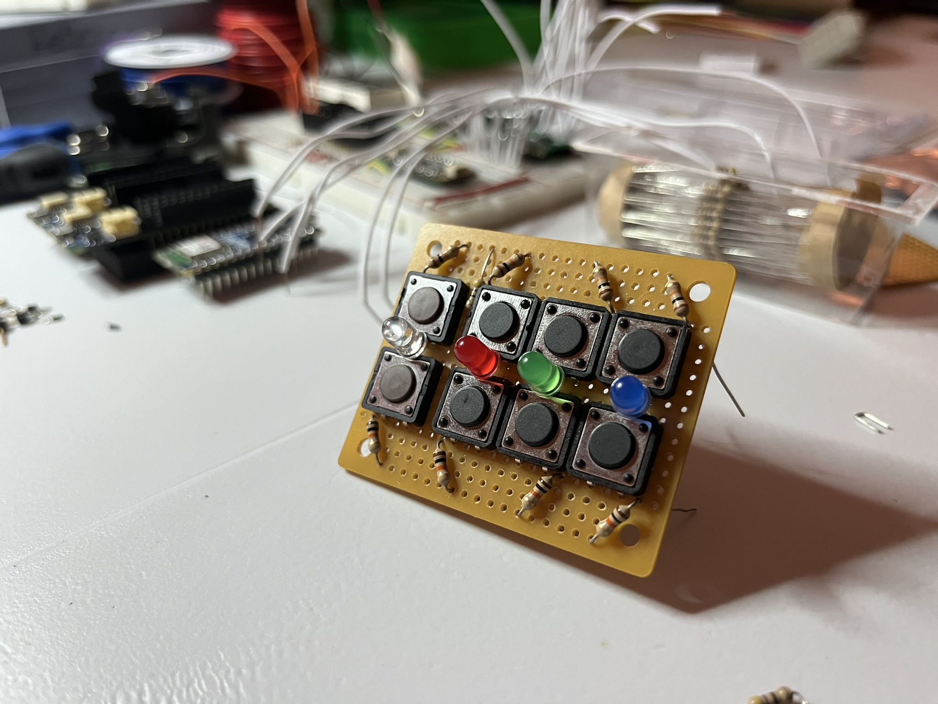
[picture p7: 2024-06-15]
docs/imgs/photos/hardware/user-control-prototype__2024-05-31.JPEG

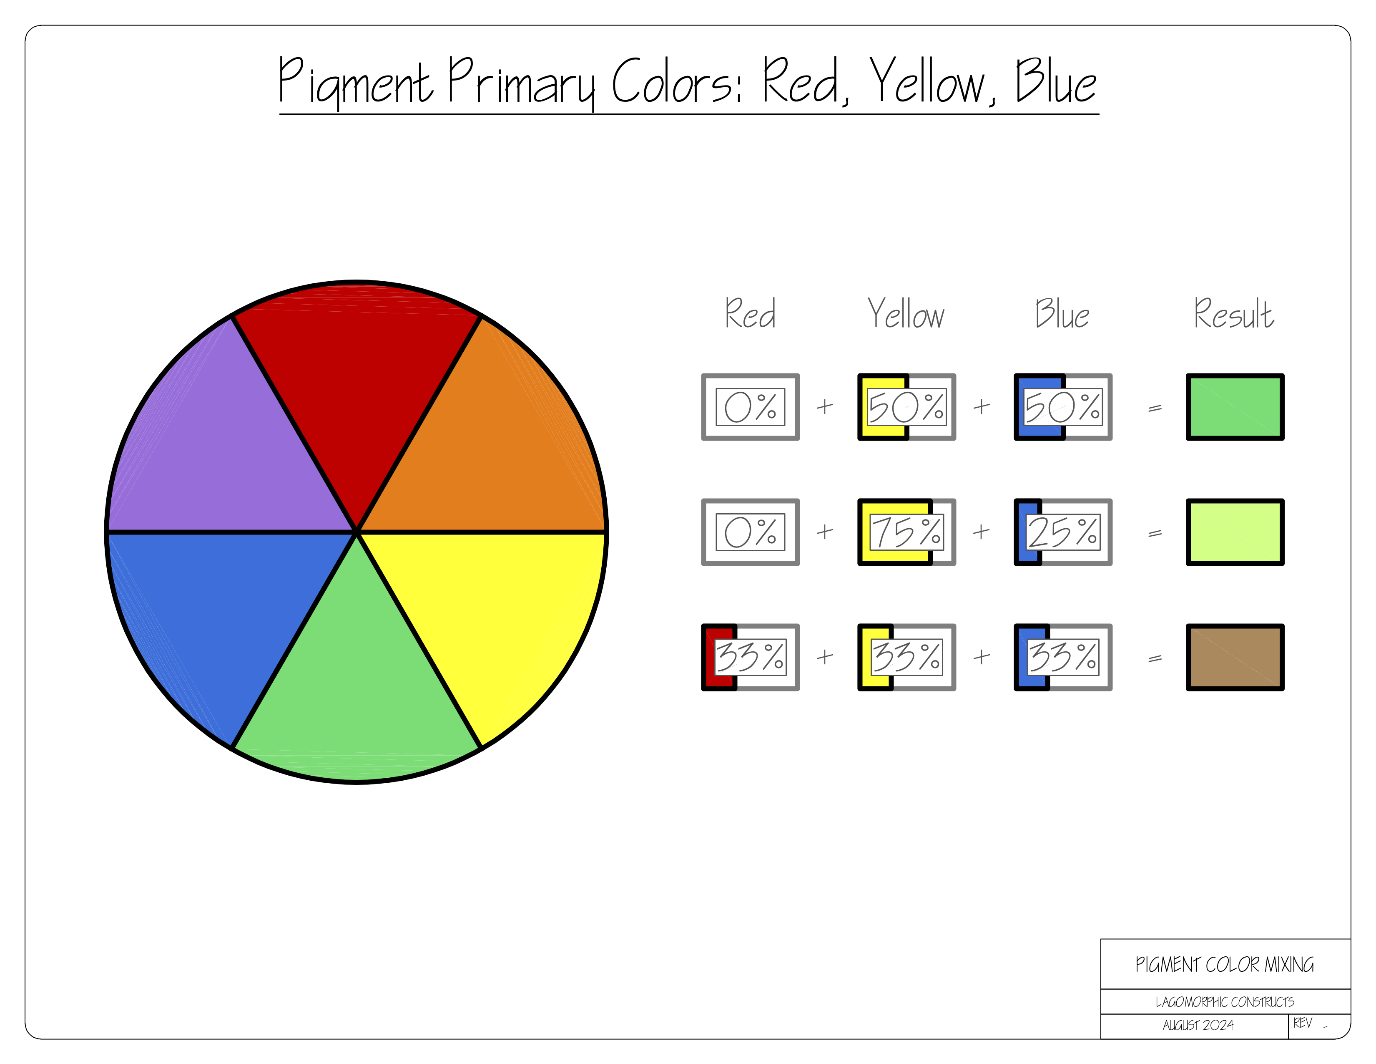
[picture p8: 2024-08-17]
docs/slide-decks/2024-08-10__demo/_png/01__pigment-color.png

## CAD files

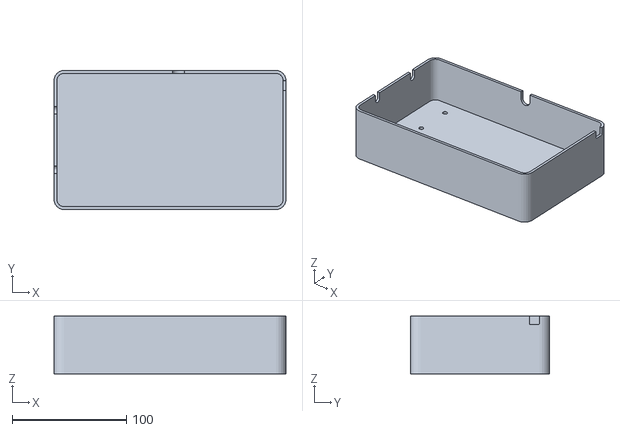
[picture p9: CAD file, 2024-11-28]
docs/imgs/acad/_stl/circuit-board-enclosure-main-v0__2027-07-23.stl
203.2 x 121.9 x 50.8

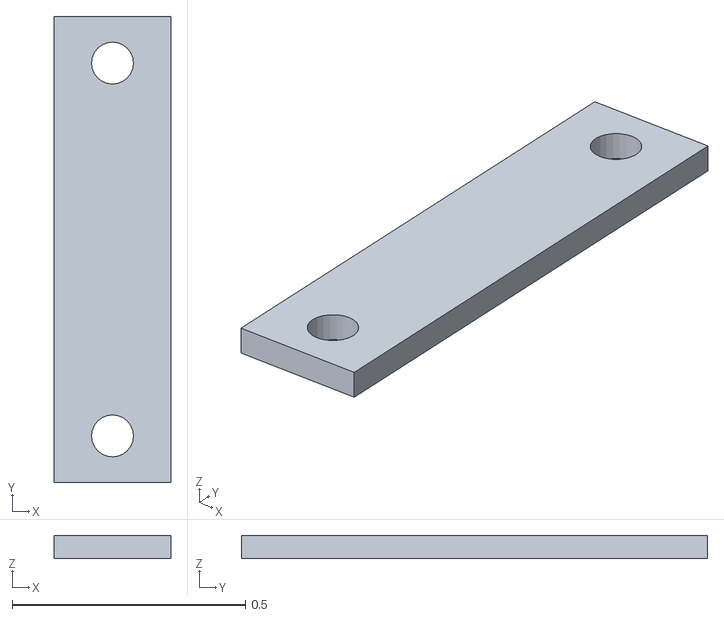
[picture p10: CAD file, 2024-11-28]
docs/imgs/acad/_stl/circuit-board-connector-.05__2027-07-15.stl
0.25 x 1.00 x 0.05

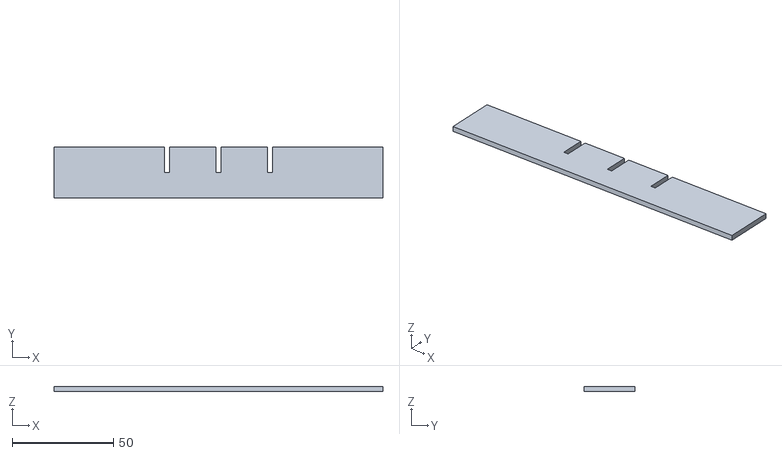
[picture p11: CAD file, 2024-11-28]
docs/imgs/acad/_stl/box-divider-6.4in-v1__2024-08-08.stl
162.6 x 25.4 x 2.54

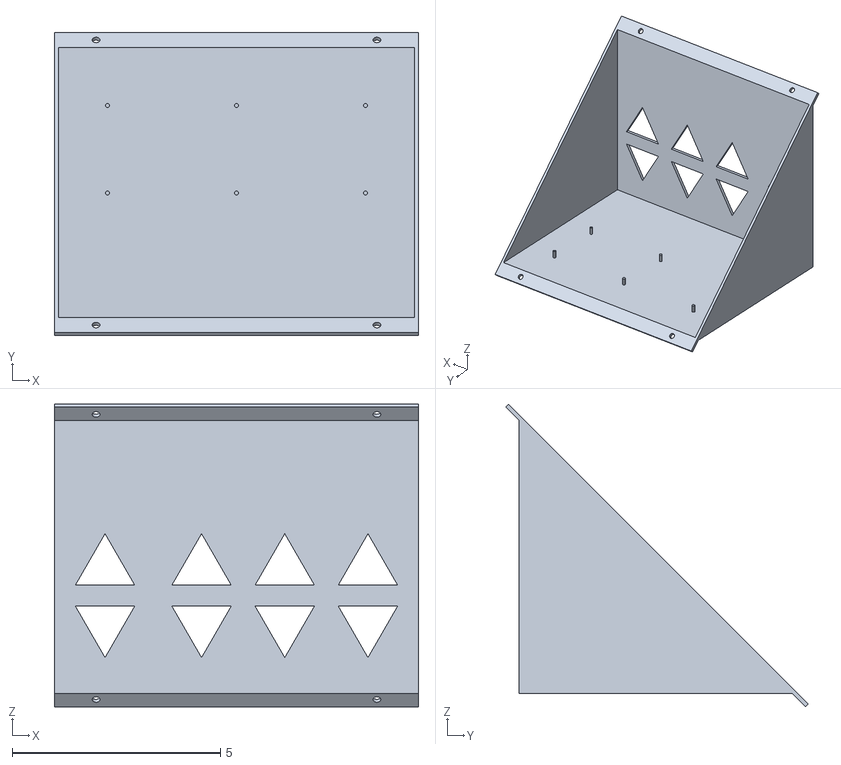
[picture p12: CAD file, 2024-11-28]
docs/imgs/acad/_stl/enclosure-color-clock-v0.stl
8.75 x 7.28 x 7.28

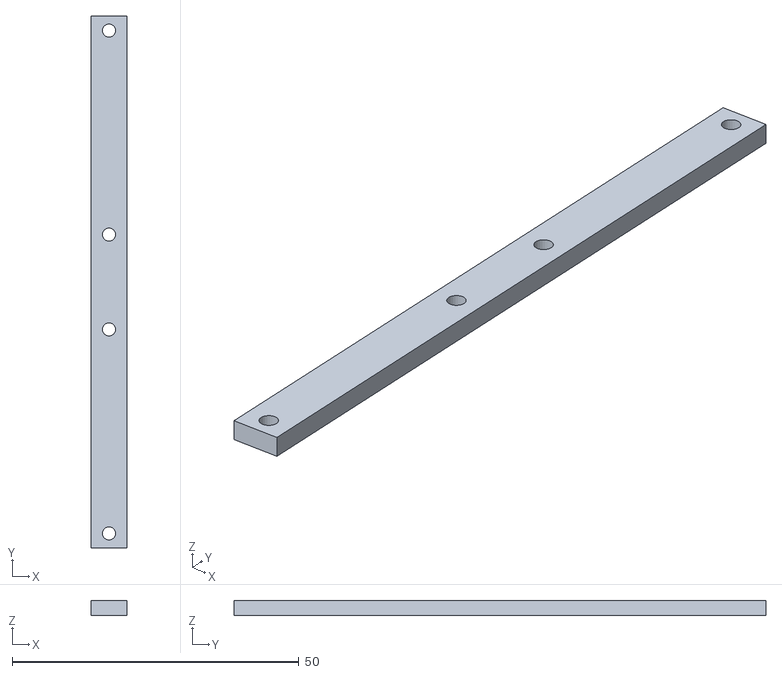
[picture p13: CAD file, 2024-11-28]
docs/imgs/acad/_stl/circuit-board-connector-0.1-long__2027-07-17.stl
6.35 x 92.7 x 2.54

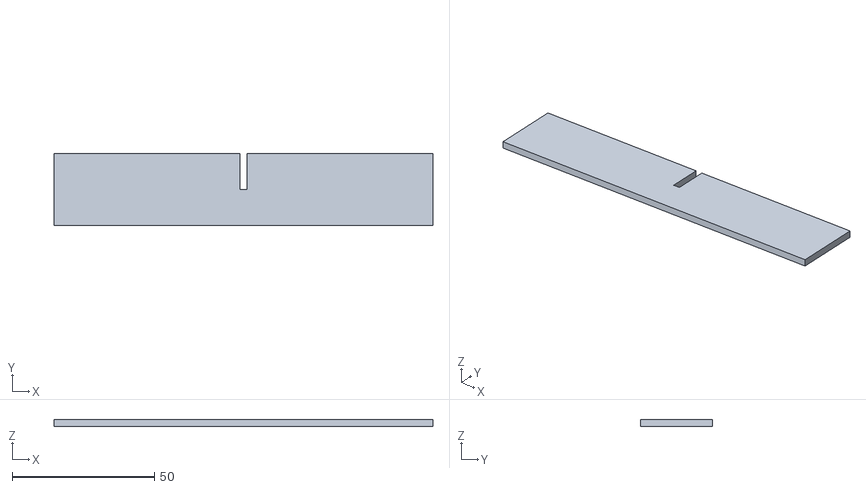
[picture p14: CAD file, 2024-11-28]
docs/imgs/acad/_stl/box-divider-4.25in-v0__2024-08-04.stl
133.4 x 25.4 x 2.54

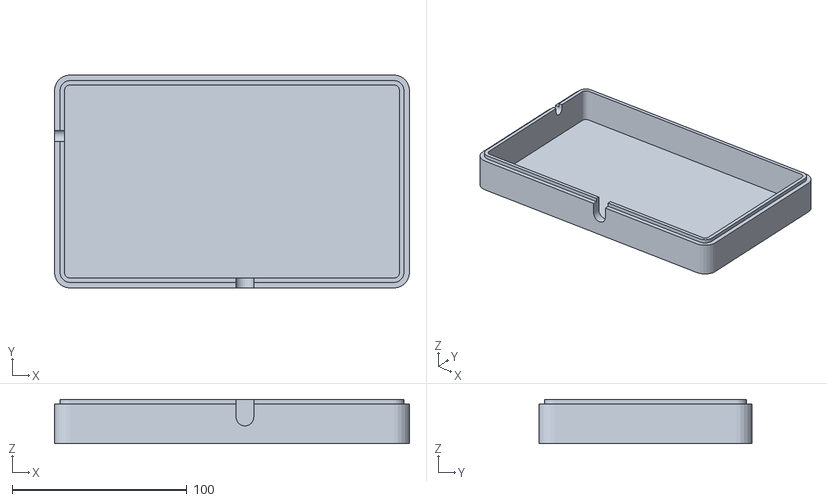
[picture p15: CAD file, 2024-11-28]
docs/imgs/acad/_stl/circuit-board-enclosure-top-v1__2028-08-11.stl
203.2 x 121.9 x 25.4

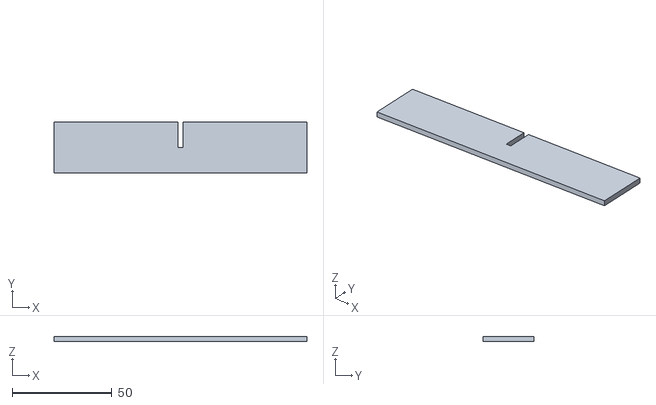
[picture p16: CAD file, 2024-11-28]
docs/imgs/acad/_stl/box-divider-4in-v0__2024-08-04.stl
127.0 x 25.4 x 2.54

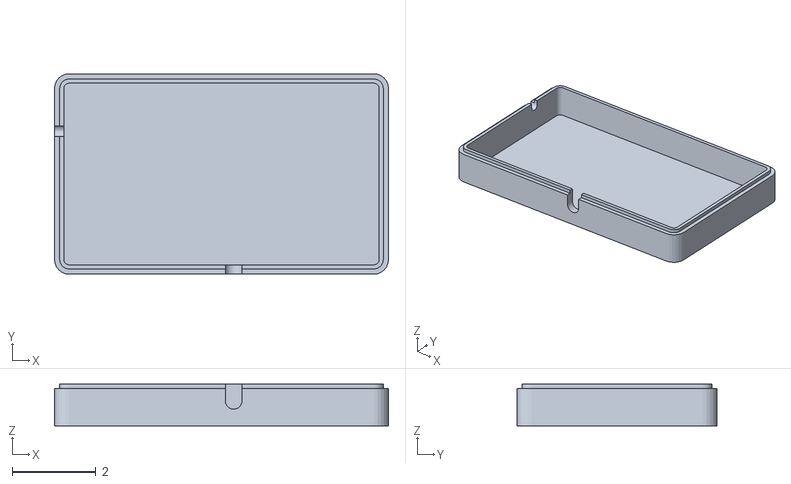
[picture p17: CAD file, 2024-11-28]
docs/imgs/acad/_stl/enclosure-top-v1__2028-08-11.stl
8.00 x 4.80 x 1

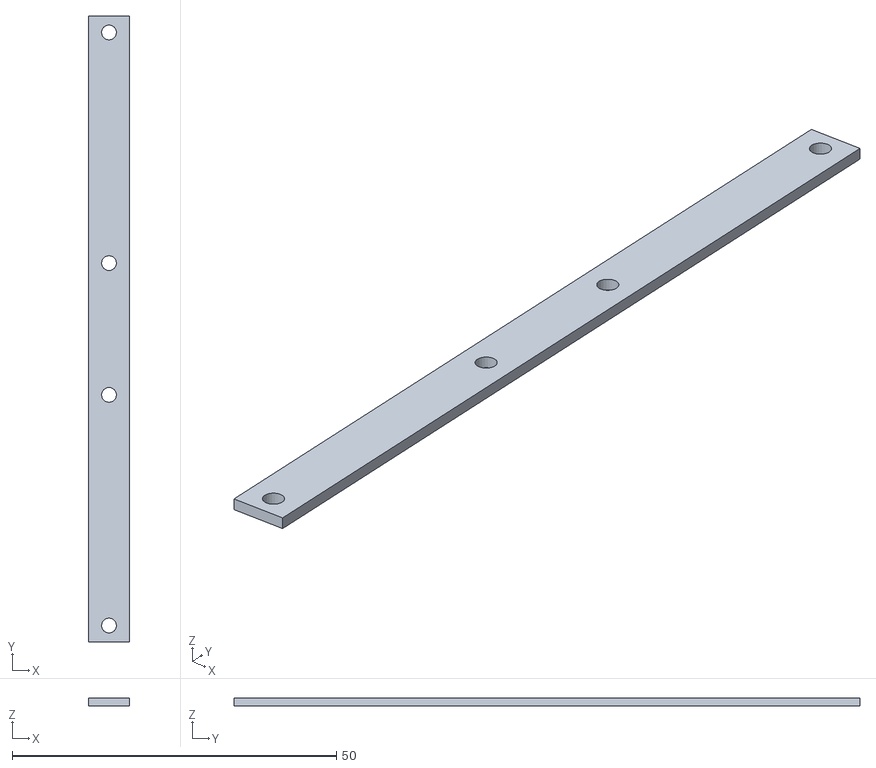
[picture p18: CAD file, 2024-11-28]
docs/imgs/acad/_stl/circuit-board-connector-.05-long__2027-07-16.stl
6.35 x 96.5 x 1.27

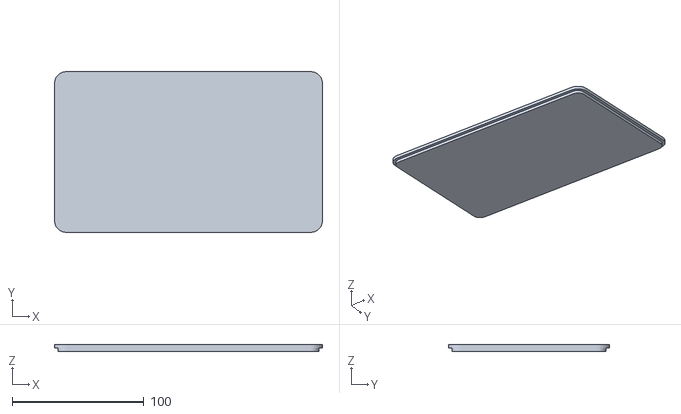
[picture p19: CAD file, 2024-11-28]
docs/imgs/acad/_stl/circuit-board-enclosure-top-v0__2027-07-23.stl
203.2 x 121.9 x 5.08

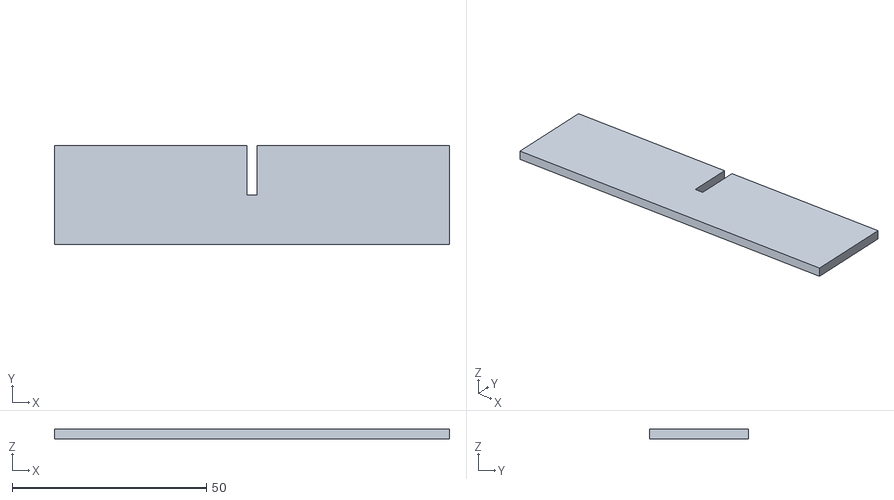
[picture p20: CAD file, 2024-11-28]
docs/imgs/acad/_stl/box-divider-4in-v1__2024-08-08.stl
101.6 x 25.4 x 2.54

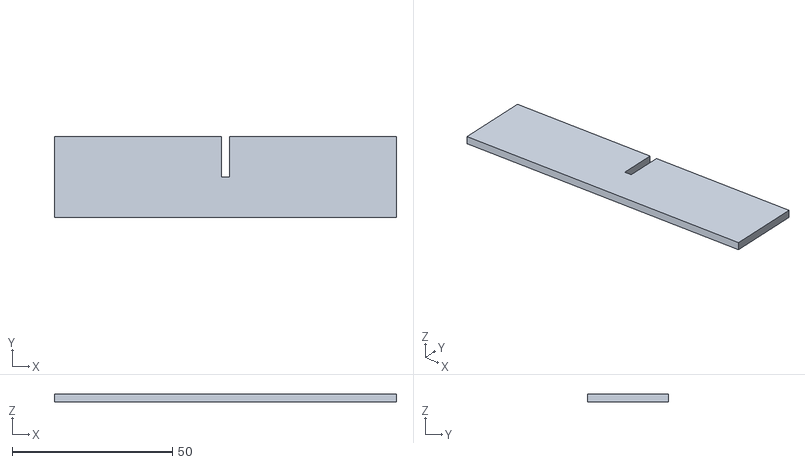
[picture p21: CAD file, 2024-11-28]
docs/imgs/acad/_stl/box-divider-4.2in-v1__2024-08-08.stl
106.7 x 25.4 x 2.54

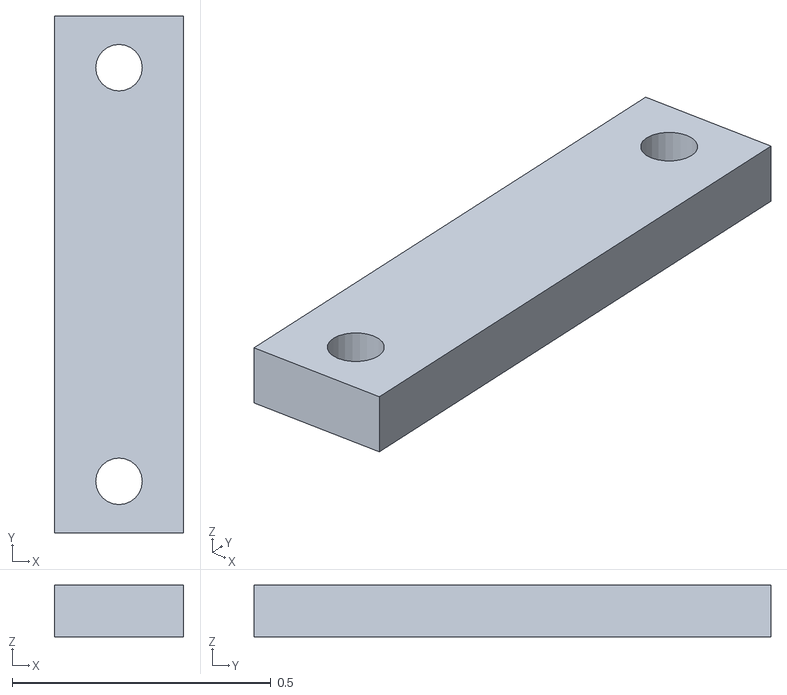
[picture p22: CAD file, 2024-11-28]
docs/imgs/acad/_stl/circuit-board-connector-0.1__2027-07-15.stl
0.25 x 1.00 x 0.1

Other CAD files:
docs/imgs/acad/acrylic-sheet/acrylic-sheet-rev.dwg
docs/imgs/acad/color-clock-3d-models.dwg
docs/slide-decks/2024-08-10__demo/color-clock-presentation.dwg
docs/imgs/acad/color-clock-electronics.dwg
docs/imgs/acad/_stl/box-divider-6in-v0__2024-08-04.stl
docs/imgs/acad/_stl/enclosure-front-v0__2024-07-29.stl

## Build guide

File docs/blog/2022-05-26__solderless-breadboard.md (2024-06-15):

# A Beautiful Breadboard

Behold! The first design of the of the fully populated solderless breadboard!

<>

This to-scale-ish design contains all of the modules that will be present on the final circuit board for ColorClock. The user interface controls are not present on this board.

In order to bring ease to the final phase of hardware testing, I thought it important to plan out the layout of the prototyping breadboard to mitigate the struggles of electronic troubleshooting. I started this layout by looking at the datasheets, obtaining the dimensions of each module, and drawing each component to scale. Then I decided it would be actually be more functional if I were using units of breadboard holes (approximately 0.1" between holes) instead of true dimensions. To determine the size represented on the diagram I placed each module on the breadboard and noted how many holes they covered and the positioning of all the pins. The next step is to actually wire this thing up and get to testing with the real LED light display 🙌

# Clock Crafting

And on the topic of the light display, it's just about finished! My partner bought a plunge base and circle jig in order to cut the circle and route out pockets for the LED strips to rest in. I'm very pleased with the results 😀

We are using a reflective metallic finish to maximize the light output, and a sheet of translucent acrylic that will sit on top to diffuse the light.

<>

The final routed wood piece features outer rings designed to house RGB LED strips. Each ring will display colors corresponding to the current time in days, hours, and minutes. The center of the piece will have a flower-like shape of LEDs that will be controllable by participant interaction via user control panel.

<>

The LEDs are glued to the inside of the pockets, and the colored light will be reflected off the metallic finish.

# IO Expander Integration Trials

In my last post, I was working on integrating the [Arduino Nano ESP32](https://store.arduino.cc/products/nano-esp32) into the project. I successfully tested this board with the new [RTC module](https://www.adafruit.com/product/3013) and the new [alphanumeric display](https://www.adafruit.com/product/2158) 🤗 But then... I was in the process of testing the [IO expander](https://www.adafruit.com/product/4886) and ended up messing with my board configuration so much that I was no longer able to upload any code to the board. Thankfully, [ptillisch](https://forum.arduino.cc/u/ptillisch/summary) came to the rescue and resolved [my issue](https://forum.arduino.cc/t/arduino-cli-and-nano-esp32-cant-upload/1261931/5) 🥳

Though I was able to talk to the Nano board, I was unable to include the [library](https://github.com/adafruit/Adafruit_AW9523) to interface with the IO expander 😭 I chased my tail for a couple of weeks before I decided to move in a different direction.

The good news was that I could interface the IO expander with the [MKR 1000](https://docs.arduino.cc/hardware/mkr-1000-wifi) that I had been testing on before I got the Nano board. Sooooo I ordered two more Arduinos, the [MKR 1010](https://docs.arduino.cc/hardware/mkr-wifi-1010/) (they no longer make the MKR 1000) and decided to move forward.

# Can I Just Get Some Variable Voltage Control??

The plan:
- **IO expander** for analog output (required to create the RGB color mixing)
- **Arduino on-board GPIO** for digital input from user interface

When the new boards came in, I promptly began testing the IO expander. I was able to get the digitalWrite functions to work with ease, but I struggled with the analogWrite function. After days of banging my head against the wall 😖 my new contingency plan was to swap the IO functionality of the on-board Arduino GPIO and the IO expander, i.e. the IO expander for the digital IO and Arduino PWM for the RGB LED control.

ColorClock has four light strips and three variable voltage lines per strip (one for each red, green and blue) so I need exactly 12 PWM pins. According to the [product page](https://store-usa.arduino.cc/products/arduino-mkr-wifi-1010) for the MKR 1010, there are supposed to be 13 PWM pins on the board BUT one of those listed pins would be unusable for variable voltage output on ColorClock because it needed to be used for my I2C SCL required for communication to the various modules.

This PWM output count would leave me NO wiggle room if one of the pins didn't work as expected. My concern grew when I noticed that the [datasheet](https://docs.arduino.cc/resources/datasheets/ABX00023-datasheet.pdf) had conflicting information from the [product website](https://store-usa.arduino.cc/products/arduino-mkr-wifi-1010) on which pins were capable of PWM output (see the notes at the end of this post for more information).

So, to get some clarity, I manually tested each individual pin. I wrote a tiny test program and hooked up a simple circuit with an LED where I varied the output voltage. I observed the LED to see if the light got brighter as the value of the output increased. I discovered a more discrepancies between my empirical testing and the documentation  (see notes).

<>

We spent the afternoon at a brewery where I performed my variable output voltage test while my partner played his Steam Deck killing zombies or something.

# Wiring Matters
The inconsistency between my findings and the documentation left me uneasy, so I went back to testing the IO expander with a minimal example. I knew my code was solid, so I double-checked the circuit wiring and sure enough, there was a mistake. After fixing it, I was able to see a variable output voltage on a multimeter using the analogWrite function using the IO expander 🎉 So now I'm back to the original plan of using the IO expander to control the lights, and the on-board GPIO for the digital inputs.

The voltage I measured with the multimeter didn’t quite match up with the input values I expected, so it looks like I’ll need to write some calibration functions so I can programmatically compensate for hardware characteristics.

# Moving Forward

So, next steps will be:
- Wire up the breadboard so beautifully depicted above.
- Characterize the RGB LED strip, so I can programmatically adjust for the non-linear relationship between the IO expander's output voltage and the visible color from the lights.

We've got 2 1/2 months and counting... 😅

---
# Notes

## Arduino MKR 1010 PWM Pins
According to the MKR 1010 [product website](https://store-usa.arduino.cc/products/arduino-mkr-wifi-1010), the following pins are available for PWM out:
```
0 .. 8, 10, 12, A3, A4
```

According to the MKR 1010 [datasheet](https://docs.arduino.cc/resources/datasheets/ABX00023-datasheet.pdf) the following pins are available for PWM out:
```
0 .. 9
```

According to my empirical testing, the following pins are available for variable voltage output:
```
0 .. 8, 10, A3, A4, A0* **
```

\* I learned that the A0 pin provides a true analog output, not a PWM signal which is why it was listed on neither the website nor the datasheet as a PWM pin. [This page](https://resources.pcb.cadence.com/blog/2021-how-and-why-to-convert-analog-signals-to-pwm-signals) describes the difference between analog and PWM output.

\*\* Pins 9 and 10, as listed on the datasheet and website, respectively, did not produce a variable output voltage in my experiment.

## IO Expander Adafruit AW9523
There have been others that have had issues integrating the Adafruit_AW9523 [library](https://github.com/adafruit/Adafruit_AW9523) with the Arduino Nano ESP32. Though the [GitHub issues page](https://github.com/adafruit/Adafruit_AW9523/issues/6) states that this issue was resolved, I'm not so sure it was...

---
LinkedIn post

Drawing on insights from Adam Grant's "Think Again," I've actively embraced the concept of pivoting in response to unexpected outcomes, as seen in my recent IO expander integration for ColorClock. With 10 weeks until delivery, integration testing for our art installation's MVP begins. Adaptability is crucial for project completion.

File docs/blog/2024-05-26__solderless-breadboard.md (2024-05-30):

# A Beautiful Breadboard

Behold! The first design of the of the fully populated solderless breadboard!

<>

This to-scale-ish design contains all of the modules that will be present on the final circuit board for ColorClock. The user interface controls are not present on this board.

🌈

To streamline the final phase of hardware testing and preempt the challenges of electronic troubleshooting, I found it important to meticulously design the layout of the prototyping breadboard. I started this layout by looking at the datasheets, obtaining the dimensions of each module, and drawing each component to scale. Then I decided it would be actually be more functional if I were using units of breadboard holes (approximately 0.1" between holes) instead of true dimensions. To determine the size represented on the diagram I placed each module on the breadboard and noted how many holes they covered and the positioning of all the pins. The next step is to actually wire this thing up and get to testing with the real LED light display 🙌

# Clock Crafting
And on the topic of the light display, it's just about finished! My partner bought a plunge base and circle jig in order to cut the circle and route out pockets for the LED strips to rest in. I'm very pleased with the results 😀 We are using a reflective metallic finish to maximize the light output, and a sheet of translucent acrylic that will sit on top to diffuse the light.

<>

The final routed wood piece features outer rings designed to house RGB LED strips. Each ring will display colors corresponding to the current time in days, hours, and minutes. The center of the piece will have a flower-like shape of LEDs that will be controllable by participant interaction via user control panel.

<>

The LEDs are glued to the inside of the pockets, and the colored light will be reflected off the metallic finish.

# IO Expander Integration Trials

In my last post, I was working on integrating the [Arduino Nano ESP32](https://store.arduino.cc/products/nano-esp32) into the project. I successfully tested this board with the new [RTC module](https://www.adafruit.com/product/3013) and the new [alphanumeric display](https://www.adafruit.com/product/2158) 🤗 But then... I was in the process of testing the [IO expander](https://www.adafruit.com/product/4886) and ended up messing with my board configuration so much that I was no longer able to upload any code to the board. Thankfully, [ptillisch](https://forum.arduino.cc/u/ptillisch/summary) came to the rescue and resolved [my issue](https://forum.arduino.cc/t/arduino-cli-and-nano-esp32-cant-upload/1261931/5) 🥳

Though I was able to talk to the Nano board, I was unable to include the [library](https://github.com/adafruit/Adafruit_AW9523) to interface with the IO expander 😭 I chased my tail for a couple of weeks before I decided to move in a different direction (see notes).

The good news was that I could interface the IO expander with the [MKR 1000](https://docs.arduino.cc/hardware/mkr-1000-wifi) that I had been testing on before I got the Nano board. Sooooo I ordered two more Arduinos, the [MKR 1010](https://docs.arduino.cc/hardware/mkr-wifi-1010/) (they no longer make the MKR 1000) and decided to move forward.

# Can I Just Get Some Variable Voltage Control??

The plan:
- Use the **IO expander** for analog output (required to create the RGB color mixing)
- Use the **Arduino on-board GPIO** for digital input from user interface

When the new boards came in, I promptly began testing the IO expander. I was able to get the digitalWrite functions to work with ease, but I struggled with the analogWrite function. After days of banging my head against the wall 😖 my new contingency plan was to swap the IO functionality of the on-board Arduino GPIO and the IO expander, i.e. the IO expander for the digital IO and Arduino PWM for the RGB LED control.

ColorClock has four light strips and three variable voltage lines per strip (one for each red, green and blue) so I need exactly 12 PWM pins. According to the [product page](https://store-usa.arduino.cc/products/arduino-mkr-wifi-1010) for the MKR 1010, there are supposed to be 13 PWM pins on the board BUT one of those listed pins would be unusable for variable voltage output on ColorClock because it needed to be used for my I2C SCL required for communication to the various modules.

This PWM output count would leave me NO wiggle room if one of the pins didn't work as expected. My concern grew when I noticed that the [datasheet](https://docs.arduino.cc/resources/datasheets/ABX00023-datasheet.pdf) had conflicting information from the [product website](https://store-usa.arduino.cc/products/arduino-mkr-wifi-1010) on which pins were capable of PWM output (see the notes at the end of this post for more information).

So, to get some clarity, I manually tested each individual pin. I wrote a tiny test program and hooked up a simple circuit with an LED where I varied the output voltage. I observed the LED to see if the light got brighter as the value of the output increased. I discovered a more discrepancies between my empirical testing and the documentation (see notes).

<>

We spent the afternoon at a brewery where I performed my variable output voltage test while my partner played his Steam Deck killing zombies or something.

# Wiring Matters
The inconsistency between my findings and the documentation left me uneasy, so I went back to testing the IO expander with a minimal example. I knew my code was solid, so I double-checked the circuit wiring and sure enough, there was a mistake. After fixing it, I was able to see a variable output voltage on a multimeter using the analogWrite function using the IO expander 🎉 So now I'm back to the original plan of using the IO expander to control the lights, and the on-board GPIO for the digital inputs.

The voltage I measured with the multimeter didn’t quite match up with the input values I expected, so it looks like I’ll need to write some calibration functions so I can programmatically compensate for hardware characteristics.

# Moving Forward

So, next steps will be:
- Wire up the breadboard so beautifully depicted above.
- Characterize the RGB LED strip, so I can programmatically adjust for the non-linear relationship between the IO expander's output voltage and the visible color from the lights.

We've got 2 1/2 months and counting... 😅

---
# Notes

## IO Expander Adafruit AW9523
There have been others that have had issues integrating the Adafruit_AW9523 [library](https://github.com/adafruit/Adafruit_AW9523) with the Arduino Nano ESP32. Though the [GitHub issues page](https://github.com/adafruit/Adafruit_AW9523/issues/6) states that this issue was resolved, I'm not so sure it was...

## Arduino MKR 1010 PWM Pins
According to the MKR 1010 [product website](https://store-usa.arduino.cc/products/arduino-mkr-wifi-1010), the following pins are available for PWM out:
```
0 .. 8, 10, 12, A3, A4
```

According to the MKR 1010 [datasheet](https://docs.arduino.cc/resources/datasheets/ABX00023-datasheet.pdf) the following pins are available for PWM out:
```
0 .. 9
```

According to my empirical testing, the following pins are available for variable voltage output:
```
0 .. 8, 10, A3, A4, A0* **
```

\* I learned that the A0 pin provides a true analog output, not a PWM signal which is why it was listed on neither the website nor the datasheet as a PWM pin. [This page](https://resources.pcb.cadence.com/blog/2021-how-and-why-to-convert-analog-signals-to-pwm-signals) describes the difference between analog and PWM output.

\*\* Pins 9 and 12, as listed on the datasheet and website, respectively, did not produce a variable output voltage in my experiment.

---
LinkedIn post

Reflecting on Adam Grant's "Think Again," I've actively embraced the concept of pivoting in response to unexpected outcomes, as seen in my recent attempts to interface with an IO expander for ColorClock. With 10 weeks until delivery, integration testing for our art installation's MVP begins. Adaptability is crucial for project completion. #colorclockevolution

---
Instagram post

As some of you know, this year my partner and I are finally bringing to fruition a passion project I've been developing for a decade: ColorClock. It's been refreshing to channel my creative energy and technical skills into something personal. I'm thrilled to announce that we will be displaying this interactive art piece at Burning Man 2024 🤗 Creative expression is self-care.

I've been blogging about it at rebeccajr.com/color-clock

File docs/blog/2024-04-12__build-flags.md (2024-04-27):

Build flags? Please?
Every software hurdle feels like an epic journey. My latest challenge was learning how to set build flags.

Background
I have a class called ColorClock with a member variable, clock_, which is of type DS3231, a real-time clock (RTC) module that keeps time. There's a simple API to interact with this object over I2C. A ColorClock object uses clock_ to get the current time in order to determine which color to display.  E.g.

#include <DS3231.h>  

class ColorClock {
  private:
    DS3231 clock_;

  //...
}

RgbColor ColorClock::time_to_color() {
  //...

  float the_hr  = (float) clock_->get_hr();

  //...
}
Right now the only application for a ColorClock object is in the the context of the physical light installation. However, there might be an application in the future where I want to use the `ColorClock` class in a different project with different hardware, or just for a general purpose computer application. Due to the possibility of using this code with a variety of different hardware configurations, I wanted to make the ColorClock class more modular, and not have the code directly tied to the RTC module mentioned above.

So, I decided to make a wrapper class for the clock, which I'm going to call FluxClock*. The intention of this class would be a general clock object that I can use to get or set the time. I would have build environment variables that tell the compiler to include or exclude certain parts of the code. For example, the FluxClock::get_month() function would look like this:

#if ARDUINO_BUILD
#include <DS3231.h>
#else
#include <ctime>
#endif
//_________________________________________________________________
byte FluxClock::get_month()
{
#if ARDUINO_BUILD //_________________________________________________________________
// The century_bit toggles when there is roll-over to a new
// century, e.g. from year 2099 to 2100. The century_bit will
// likely never be relevant for any use case for this code base.
//_________________________________________________________________
  bool century_bit;
  return rtc_.getMonth(century_bit);
#else
  time(&clock_);
  time_ = localtime(&clock_);
  return time_->tm_mon;
#endif
}
//_________________________________________________________________
My challenge was to figure out how to set these build environment variables so that the compiler would only compile what was necessary for the specific build configuration.

The things that didn't work

Define it in a header file
Initially, I included the macro definition, ARDUINO_BUILD in a separate file called macros.h:

#define ARDUINO_BUILD 1
I included macros in ColorClock.hpp:

#include "macros.h"
A more experienced software engineer, or even just someone who's taken a compiler class (it's on my list of things to do) would probably know immediately why this didn't work. But with my limited time, I was less interested in the why-it-doesn't-work part; I was more in the in the how-do-I-get-it-to-work mindset (though feel free to school me on this topic).

Build properties in arduino.json
For reasons mentioned in a previous post, I (was) using the Microsoft Visual Studio Code Arduino plugin to build and upload my code. The internet told me that I could set build environment variables in the arduino.json file but this didn't work either 😕

(I don't actually remember the syntax I used in arduino.json - maybe something with defines (?)  - otherwise I would have included it here as something not to do...)

Windows Arduino Command Line
So then I decided to ditch the plugin and go back to command line using arduino-cli (on Windows).  I tried using the arduino-cli command in Git Bash, and PowerShell but Windows didn't recognize the command. So I downloaded arduino-cli and stuck the arduino-cli.exe file right in my code directory and Git Bash finally found it when I ran ./arduino-cli. I realize now that I probably just needed to add the location of arduino-cli.exe to my path, but yeah, I was just in a frenzy trying to get something to work. I made a minimal example without any build flags and spent way too much time just figuring out how to set the right serial port so I could upload the code to the board. But I was able to figure that part out.

Now on to the build flags problem... I tried many variations of setting a build flag (FLUX) in the command line argument of arduino-cli compile. But the compiler spit out all sorts of weird errors with every variation. Don't use this command, it doesn't work:

arduino-cli compile --fqbn arduino:samd:mkr1000 --build-properties build.extra_flags=-DFLUX=42

Old tech with a config file
I gave up on Windows and went back to my 10 year old MacBook and started from scratch with my familiar, safe, UNIX command line. I did more internetting (with my friend ChatGPT) and found that I should be able to set build flags in an arduino config file.

build:
  properties:
    FLUX:"42"
I set the config file path in my command line argument...

arduino-cli compile --fqbn arduino:samd:mkr1000 --config-file path/to/arduino_cli.yaml

but nope, this didn't work either. ChatGPT failed me. It then clarified that that the compiler might not actually recognize the flag 😐

And now the thing that worked

Deep in the Arduino installation directory...
Once again, after spending what seemed like ages (but was probably closer to an hour) searching on the internet and more talking to ChatGPT, I learned that I needed to edit the platform.txt file deep inside my install directory: 

Users/rebeccarashkin/Library/Arduino15/packages/arduino/hardware/samd/1.8.13/
and set my build flags in build.extra_flags:

build.extra_flags= -DFLUX=42
But this didn't work either! However, I did see a note just above the build.extra_flags line that said "These can be overridden in platform.local.txt" so I figured build.extra_flags might be getting overridden in the build process. I also read somewhere that I can also edit build flags in boards.txt. So I opened boards.txt in the same directory and found the build.extra_flags variable for my board and appended the variable that corresponded with my Arduino board, the MKR 1000

mkr1000.build.extra_flags= -DFLUX=42
Eureka! 🥳

FINALLY the compiler recognized my build flag.

It worked, but come on.
However, digging that deep into an installation directory just to set a build flag seems a little excessive, so I'd like to learn more about the platform.local.txt file. Buuuut.... for now, I really only have one build flag that I care about and I'm ok hacking my way through setting a build flag if it means I can progress in my development.

Ok, now what was I trying to do again? 😅

* Flux was my beloved rabbit companion for over 10 years and died in 2019. His memory lives on in nearly all of my software engineering endeavors.

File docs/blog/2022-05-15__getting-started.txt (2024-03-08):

Getting started? Just show up.
When starting out, avoid getting caught up in the details of implementation, and instead invest your energy in preparing to show up.

🐰

Imagine you are getting ready to do the thing. Ask yourself:

🐰

1. What equipment do I need?

2. What am I going to wear?

3. Do I need to fuel myself?

🐰

What can you prepare in advance to minimize obstacles to follow through?

🐰

For me, showing up means going to the makerspace to work on my ColorClock. I prepare by packing my bag with my computer, and my tool box with my electronics. I plan to change out from my work clothes, and to make sure I pack dinner for me and treats for Trevor (doggo).

🐰

So, what we are looking at here is a digital display showing the current minute and second that is tracked by my clock module 🤓

Circuit Diagram
I've wired up the clock module along with the debugging display. Here's where I'm at.

Software Repository
All code is hosted on my GitHub account.

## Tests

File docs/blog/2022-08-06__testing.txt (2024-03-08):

Test early. Test often. Refactor if necessary.

“It doesn’t matter how slow you progress so as long as you never stop.” I think my grad school advisor shared this with me. Maybe that wasn’t the really the quote. And maybe it wasn’t my advisor. But you get the gist 😉

ColorClock is progressing. Sllloooooowwwwwllllllyyyy. At some point during the pandemic time warp (a year ago… maybe two?), I finished coding the software prototype in Processing3. It was a window with a black background and a solid circle that changed color according to the system time. In the last year I’ve been porting that code to hardware (Arduino) so that I can fabricate an actual RGB LED wall piece or sculpture.

The Software Prototype This video demonstrates how the color changes over time. The cycle length displayed here is ~6 seconds. The current design is for the final piece to have a cycle length of 24 hours; the audience will not perceive a color change if the piece is viewed for a short time period.

A month or two ago I had to start over because I realized that I was converting code but barely testing it beyond making sure that the project built properly - and then at some point it stopped compiling 😬 And even though I was using version control, I couldn’t figure out the last commit with a known good build 😩 Though this is a personal project, it was crazy to reflect on similar challenges I have experienced in my work life.

🐰

Soooooooo…

🐰

Since then, I have added a debug class for serial monitor print statements, refactored the project to be completely object oriented, and started using branches and pull requests for my repository even though I’m the only developer.

🐰

This past week I also started exploring how to unit test portions of the code without running it on actual hardware. The Arduino language is basically C++ so I just made a small driver function where I include my classes that don’t have any Arduino dependencies. I’m proud of myself for the forethought I put in to the architecture so that I can build software only tests without needing to modify the code I’m testing 🤓

Hardware Prototyping Progress This is the state of the hardware prototype at the time of writing. The alphanumeric display will be hidden from view in the final piece. While testing the color changing capabilities, I realized that the Arduino board I'm using only has two pulse width modulation I/O pins so I can only cycle through colors that are combinations of two primary colors, like red and green, red and blue, or green and blue.

I’m actually kind of stuck at the moment - the contents of my RGB <-> HSV color conversion functions seem to be working, but not when the class definitions are included in a different file 🤷‍♀️ I’m going to stare at the code a bit more and possibly call in some reinforcements 🧑‍💻

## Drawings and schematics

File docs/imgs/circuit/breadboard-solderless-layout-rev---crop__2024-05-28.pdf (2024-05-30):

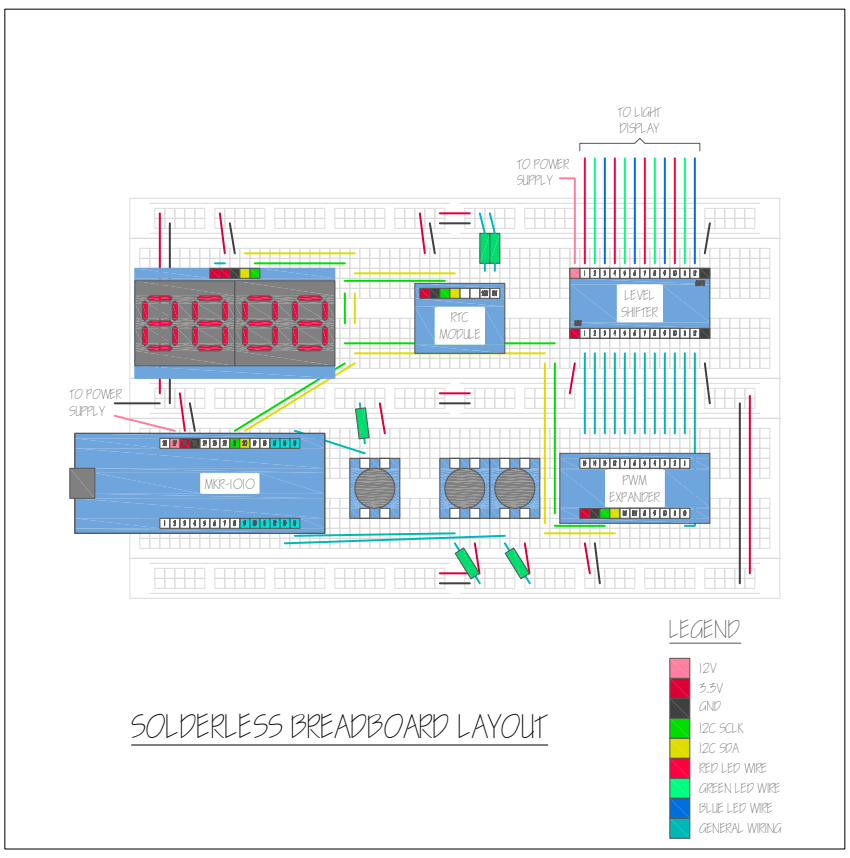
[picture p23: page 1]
LEGEND; LEVEL SHIFTER; PWM EXPANDER; RTC MODULE; MKR-1010; TO POWER SUPPLY; TO LIGHT DISPLAY

GND
I2C SCLK
I2C SDA
RED LED WIRE
GREEN LED WIRE
BLUE LED WIRE
GENERAL WIRING

SOLDERLESS BREADBOARD LAYOUT

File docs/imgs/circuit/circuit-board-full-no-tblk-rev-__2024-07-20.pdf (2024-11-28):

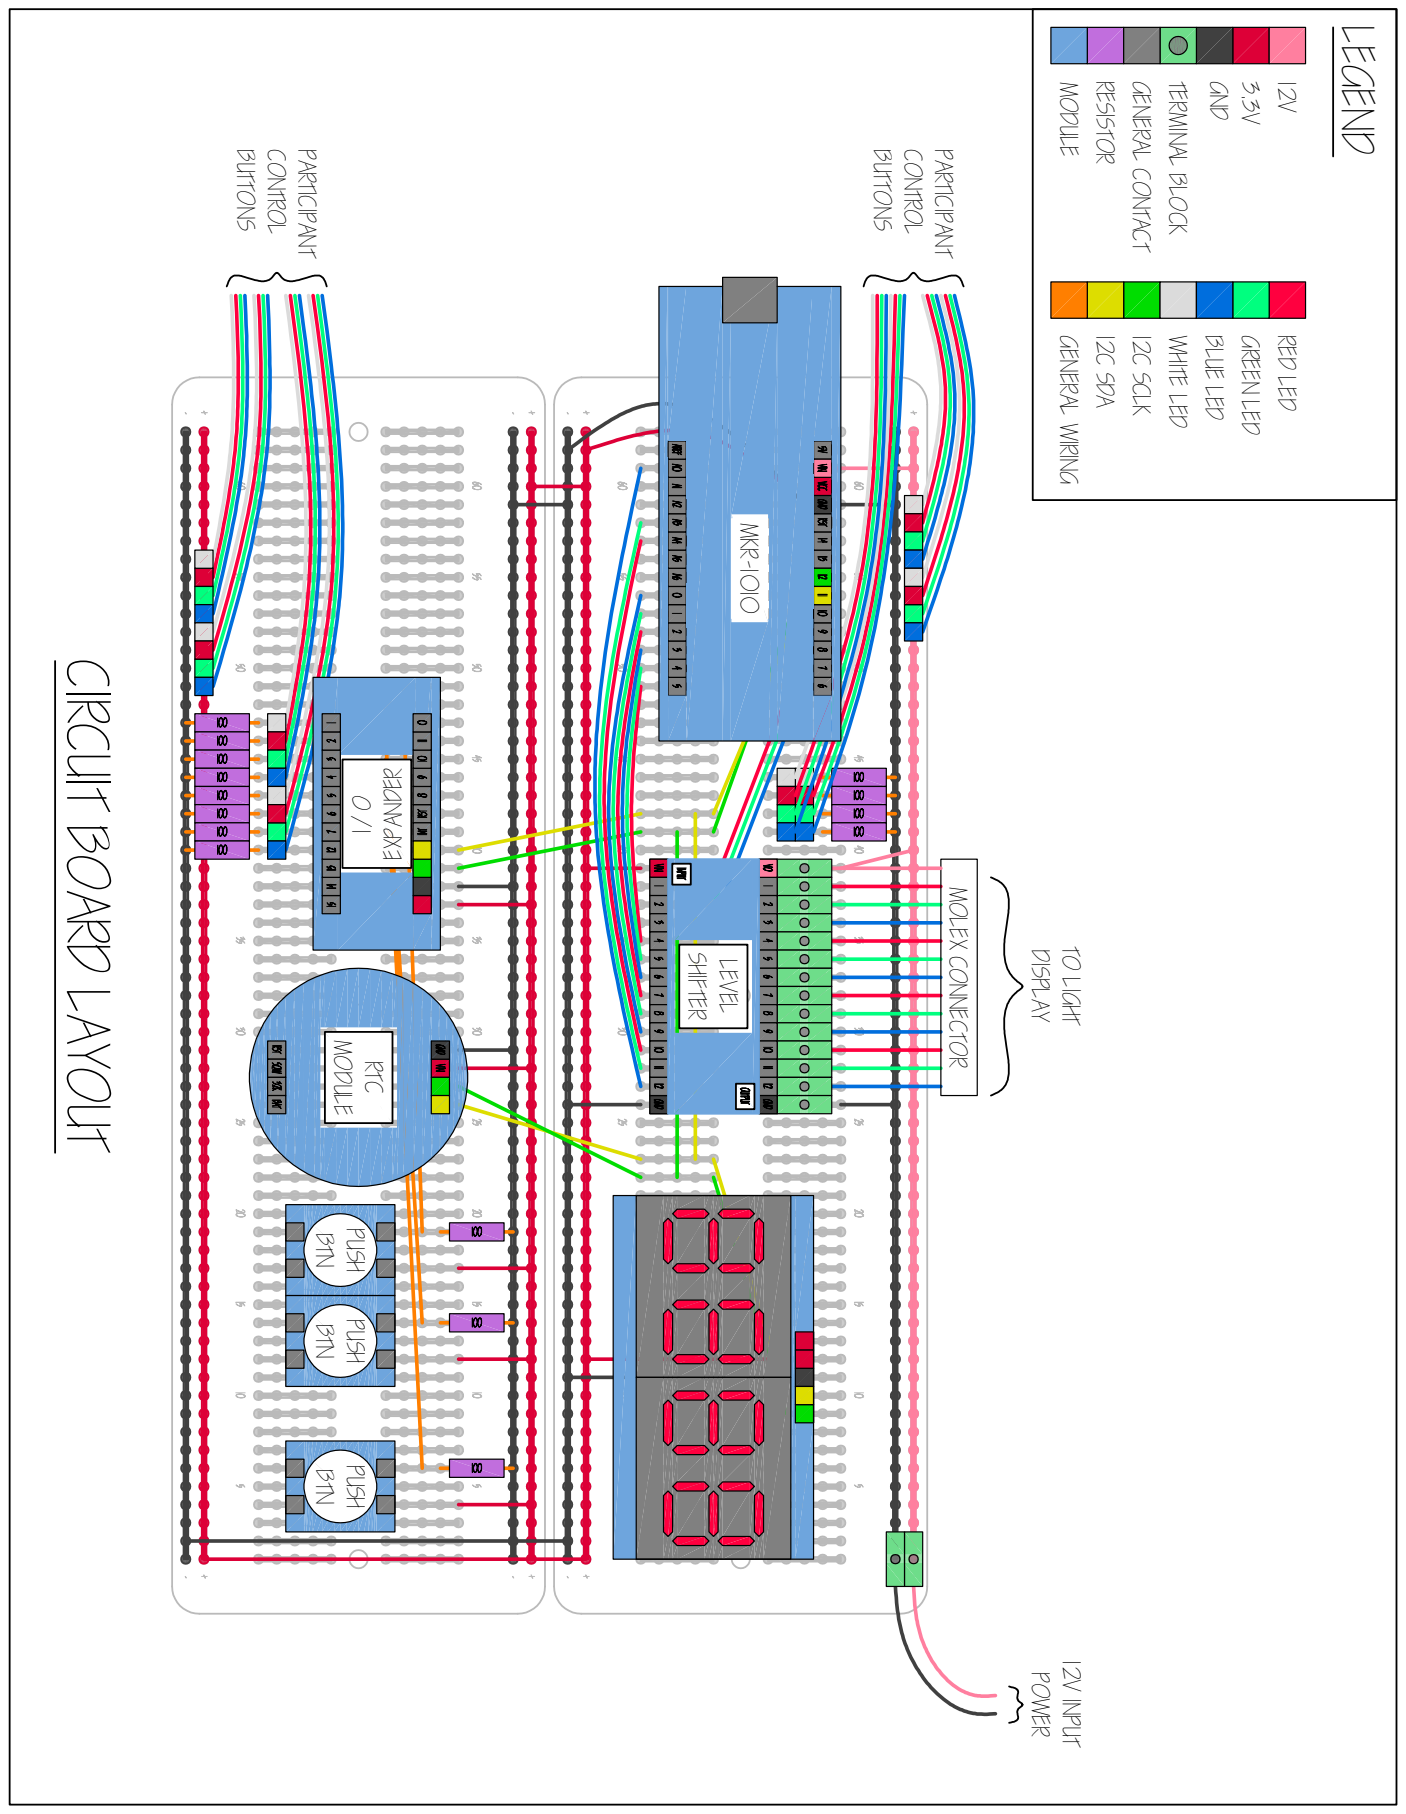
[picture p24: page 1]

BTN PUSH BTN PUSH BTN PUSH BUTTONS CONTROL PARTICIPANT MOLEX CONNECTOR DISPLAY TO LIGHT 12V INPUT POWER BUTTONS CONTROL PARTICIPANT LEVEL SHIFTER MKR-1010 RTC MODULE I/O EXPANDER 3.3V 12V RED LED I2C SDA I2C SCLK GND LEGEND RESISTOR WHITE LED GREEN LED TERMINAL BLOCK GENERAL WIRING BLUE LED MODULE GENERAL CONTACT CIRCUIT BOARD LAYOUT

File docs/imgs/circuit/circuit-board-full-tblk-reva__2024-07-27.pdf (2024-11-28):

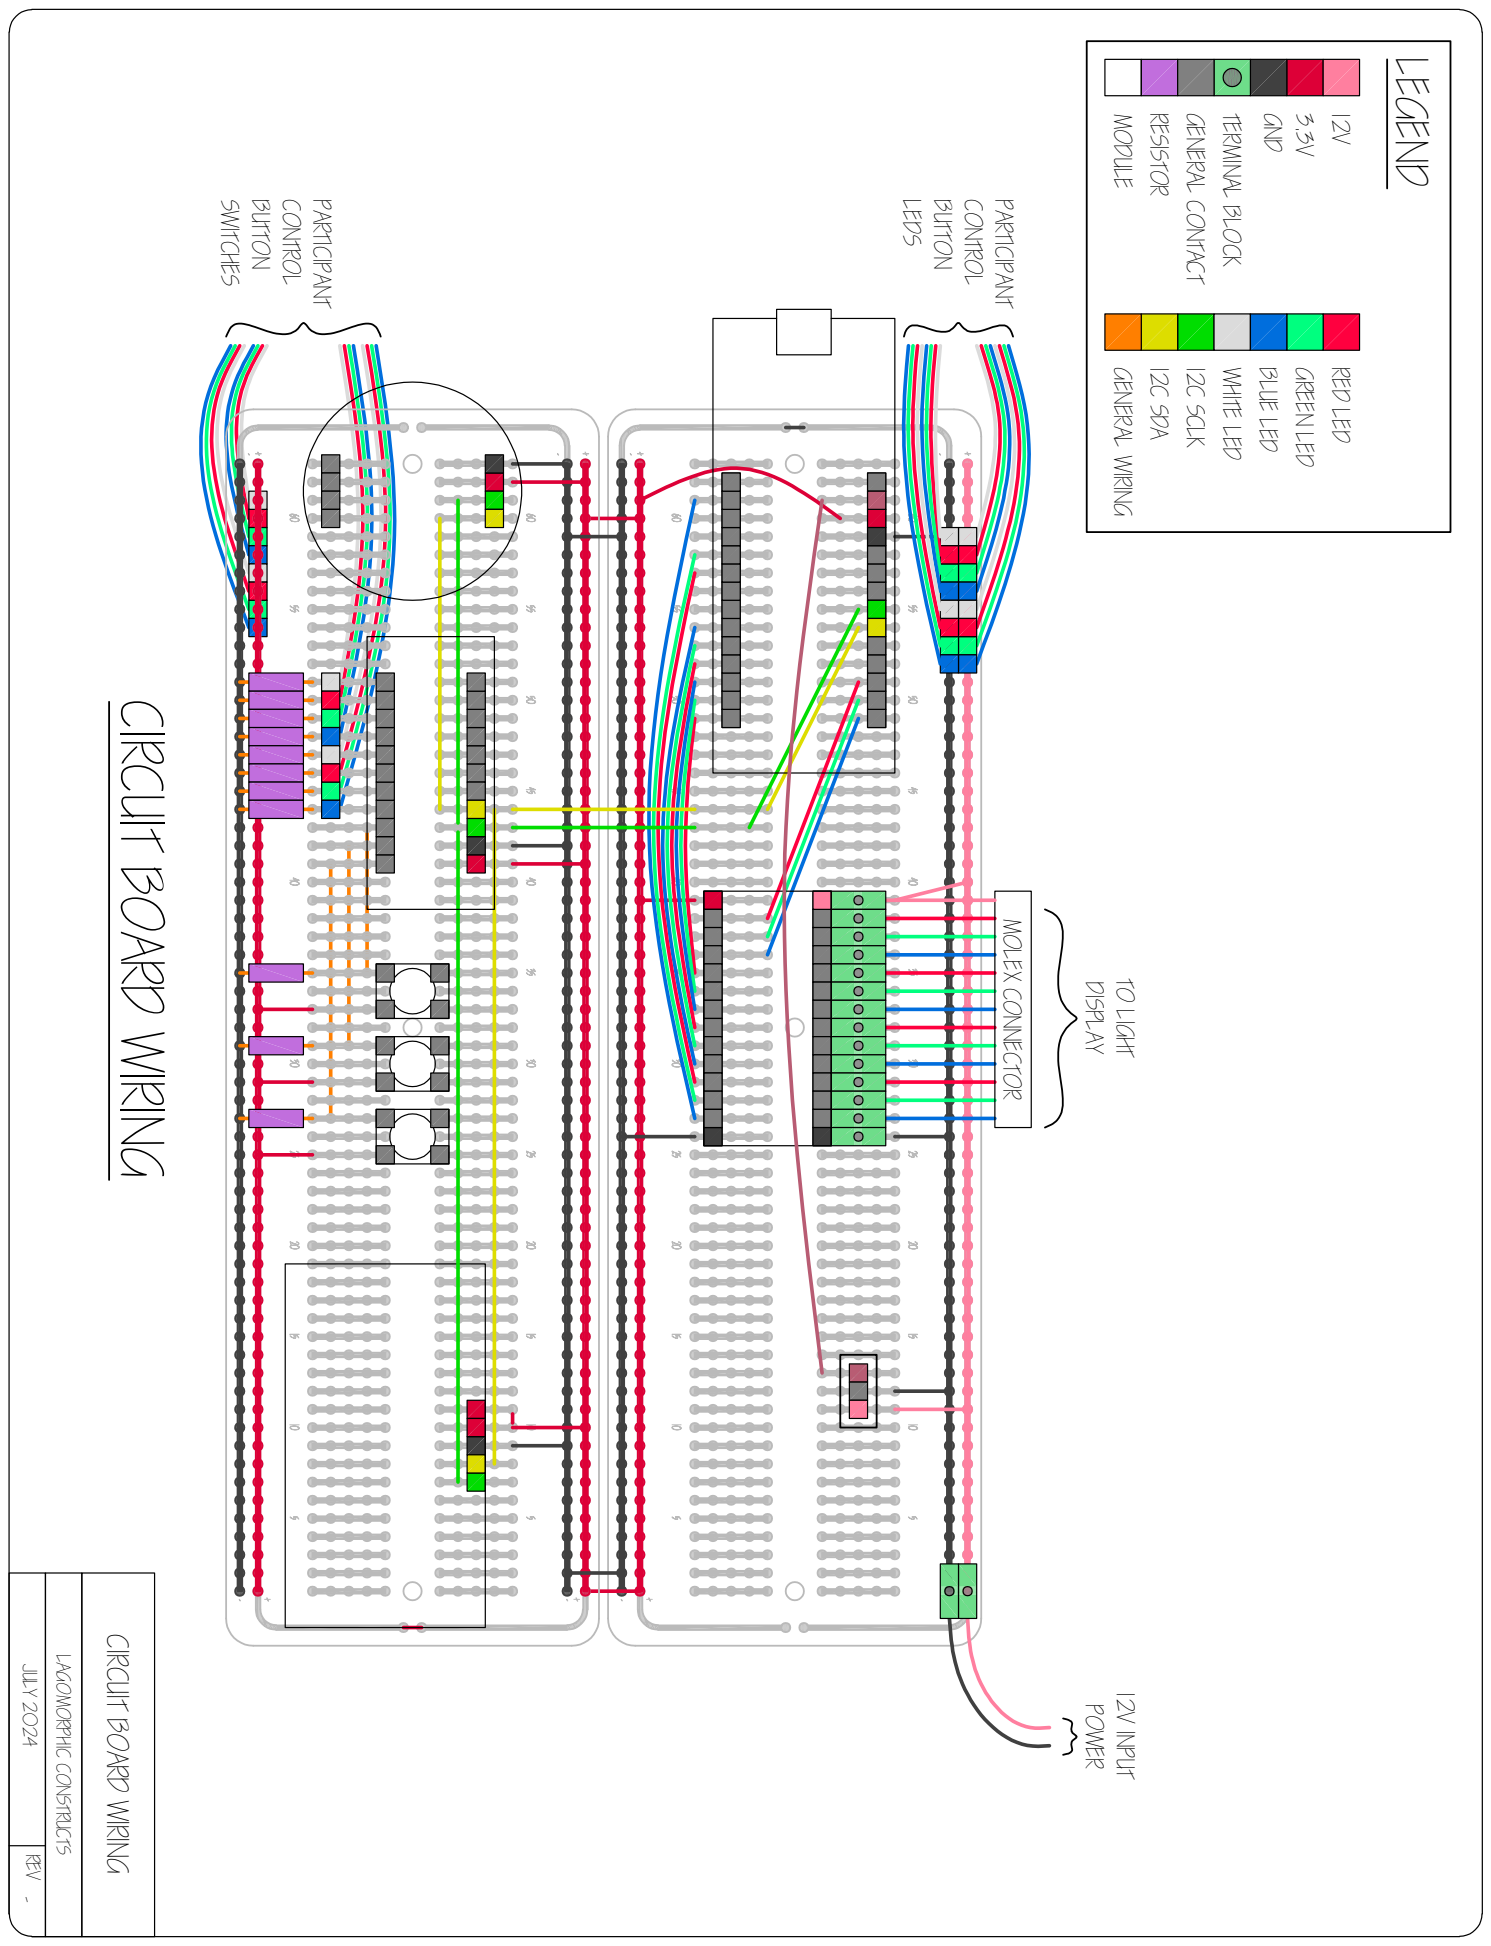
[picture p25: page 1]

3.3V 12V RED LED I2C SDA I2C SCLK GND LEGEND RESISTOR WHITE LED GREEN LED TERMINAL BLOCK GENERAL WIRING BLUE LED MODULE GENERAL CONTACT LEDS BUTTON CONTROL PARTICIPANT MOLEX CONNECTOR DISPLAY TO LIGHT 12V INPUT POWER SWITCHES BUTTON CONTROL PARTICIPANT REV LAGOMORPHIC CONSTRUCTS - JULY 2024 CIRCUIT BOARD WIRING CIRCUIT BOARD WIRING

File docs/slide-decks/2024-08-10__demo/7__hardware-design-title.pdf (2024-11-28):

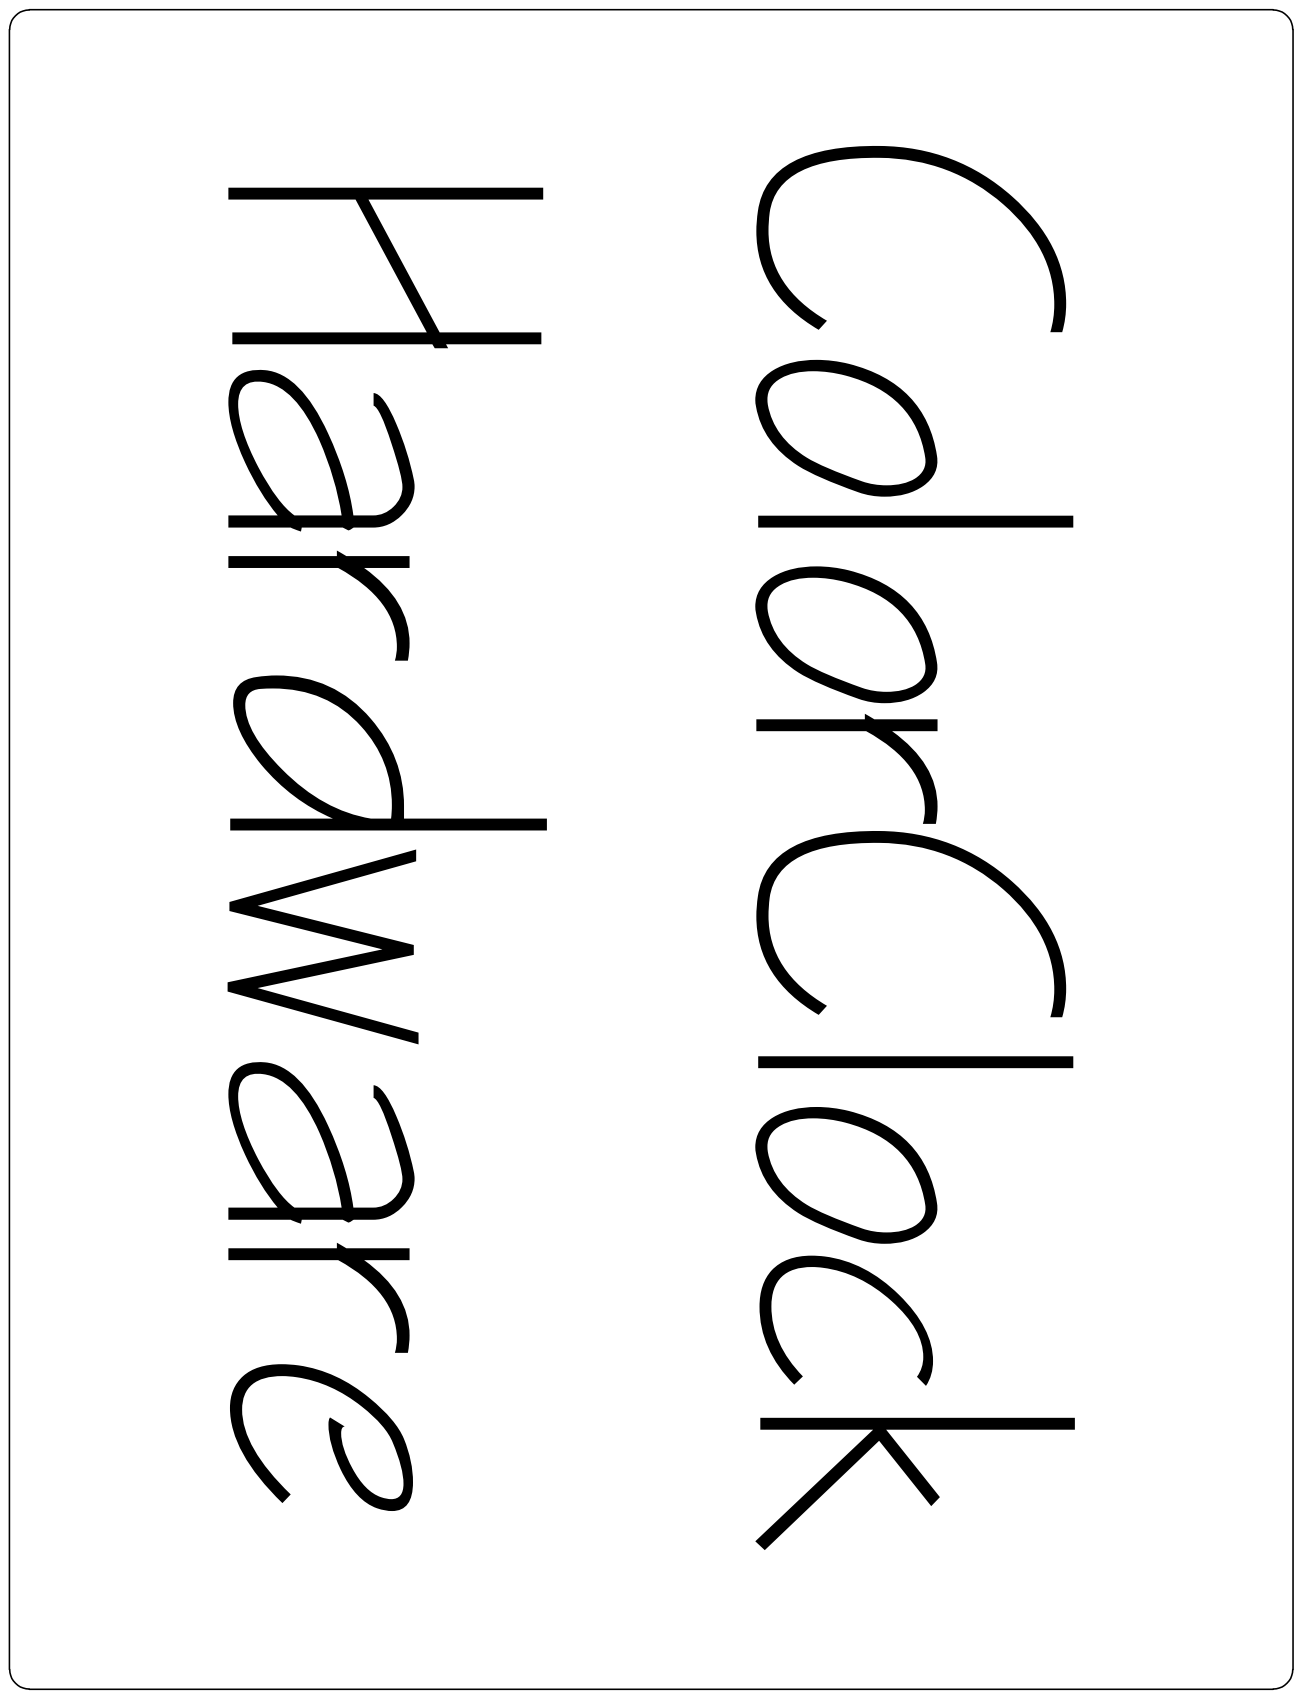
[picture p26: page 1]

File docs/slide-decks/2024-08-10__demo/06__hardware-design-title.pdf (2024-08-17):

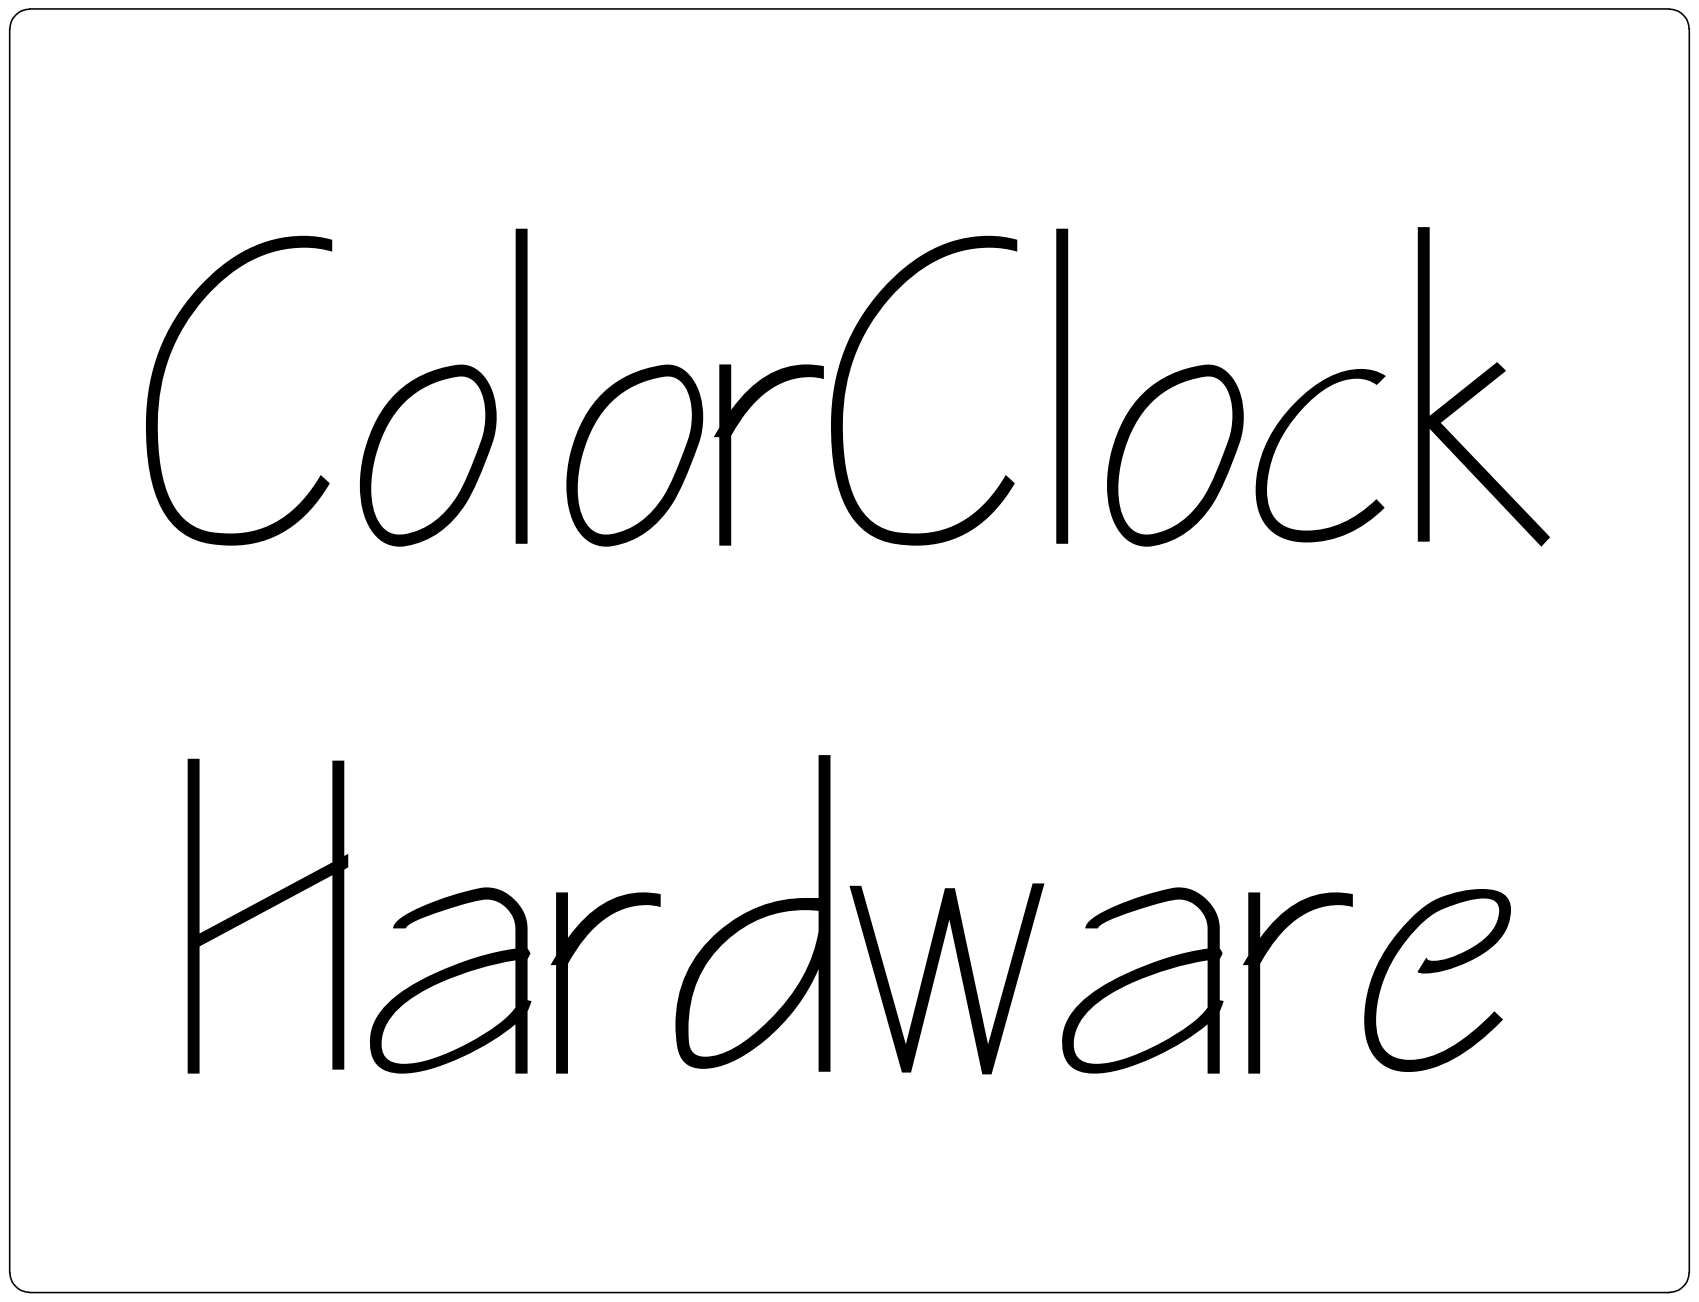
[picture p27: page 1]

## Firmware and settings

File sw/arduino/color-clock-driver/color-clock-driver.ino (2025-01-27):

//______________________________________________________________________
//______________________________________________________________________
//      _   __   _   _ _   _   _   _         _
// |   |_| | _  | | | V | | | | / |_/ |_| | /
// |__ | | |__| |_| |   | |_| | \ |   | | | \_
//  _  _         _ ___  _       _ ___   _                        / /
// /  | | |\ |  \   |  | / | | /   |   \                        (^^)
// \_ |_| | \| _/   |  | \ |_| \_  |  _/                        (____)o
//______________________________________________________________________
//______________________________________________________________________
//
//----------------------------------------------------------------------
// Copyright 2024, Rebecca Rashkin
// -------------------------------
// This code may be copied, redistributed, transformed, or built upon in
// any format for educational, non-commercial purposes.
//
// Please give me appropriate credit should you choose to use this
// resource. Thank you :)
//----------------------------------------------------------------------
//
//______________________________________________________________________
// //\^.^/\\   //\^.^/\\   //\^.^/\\   //\^.^/\\   //\^.^/\\   //\^.^/\\
//______________________________________________________________________
//______________________________________________________________________
// DESCRIPTION
// This file contains the driver for the color clock project.
//______________________________________________________________________

#include <Arduino.h>
#include <vector>
#include <Wire.h>

#include <Adafruit_AW9523.h>
#include <Adafruit_GFX.h>
#include "Adafruit_LEDBackpack.h"

#include "flux-macros.hpp"

#include "hsv-color.hpp"
#include "rgb-color.hpp"
#include "color-clock.hpp"
#include "debug.hpp"
#include "flux-clock.hpp"
#include "momentary-switch.hpp"
#include "time-calcs.hpp"
#include "time-display.hpp"
#include "top-level.hpp"


#define CC3_CYCLE_TIME_HOURS 24.0
#define CC2_CYCLE_TIME_HOURS  1.0
#define CC1_CYCLE_TIME_HOURS  1.0 / 60.0
#define CC0_CYCLE_TIME_HOURS (12.0 / SECONDS_PER_HOUR)

#define START_YEAR  24
#define START_MONTH  8

TopLevel    top_level;
TimeDisplay display;

ColorClock* cc0;
ColorClock* cc1;
ColorClock* cc2;
ColorClock* cc3;

FluxClock   the_clock;

int red_pin_0 = 8;
int grn_pin_0 = 7;
int blu_pin_0 = 6;

int red_pin_1 = 5;
int grn_pin_1 = 4;
int blu_pin_1 = 3;

int red_pin_2 = 2;
int grn_pin_2 = 1;
int blu_pin_2 = 0;

int red_pin_3 = A4;
int grn_pin_3 = A3;
int blu_pin_3 = A0;

uint8_t inc_pin   = 14;
uint8_t dec_pin   = 13;
uint8_t enter_pin = 15;


MomentarySwitch inc_sw;
MomentarySwitch dec_sw;
MomentarySwitch enter_sw;

//______________________________________________________________________
// Participant control
//______________________________________________________________________
Adafruit_AW9523 aw;

MomentarySwitch frq_inc_btn;
MomentarySwitch red_inc_btn;
MomentarySwitch grn_inc_btn;
MomentarySwitch blu_inc_btn;
MomentarySwitch frq_dec_btn;
MomentarySwitch red_dec_btn;
MomentarySwitch grn_dec_btn;
MomentarySwitch blu_dec_btn;

uint8_t frq_inc_btn_pin = 1;
uint8_t red_inc_btn_pin = 2;
uint8_t grn_inc_btn_pin = 3;
uint8_t blu_inc_btn_pin = 4;
uint8_t frq_dec_btn_pin = 5;
uint8_t red_dec_btn_pin = 6;
uint8_t grn_dec_btn_pin = 7;
uint8_t blu_dec_btn_pin = 12;
//______________________________________________________________________

float cc0_period = CC0_CYCLE_TIME_HOURS;
float cc1_period = CC1_CYCLE_TIME_HOURS;
float cc2_period = CC2_CYCLE_TIME_HOURS;
float cc3_period = CC3_CYCLE_TIME_HOURS;

//______________________________________________________________________
void setup()
{
  Serial.begin(115200);
  Serial.println("Adafruit AW9523 Constant Current LED test!");

  if (! aw.begin(IO_EXPANDER_ADDR)) {
    Serial.println("AW9523 not found? Check wiring!");
    //while (1) delay(10);  // halt forever
  }

  aw.pinMode(inc_pin, INPUT_PULLUP);
  aw.pinMode(dec_pin, INPUT_PULLUP);
  aw.pinMode(enter_pin, INPUT_PULLUP);

  aw.pinMode(frq_inc_btn_pin, INPUT_PULLUP);
  aw.pinMode(red_inc_btn_pin, INPUT_PULLUP);
  aw.pinMode(grn_inc_btn_pin, INPUT_PULLUP);
  aw.pinMode(blu_inc_btn_pin, INPUT_PULLUP);
  aw.pinMode(frq_dec_btn_pin, INPUT_PULLUP);
  aw.pinMode(red_dec_btn_pin, INPUT_PULLUP);
  aw.pinMode(grn_dec_btn_pin, INPUT_PULLUP);
  aw.pinMode(blu_dec_btn_pin, INPUT_PULLUP);


  pinMode(red_pin_0, OUTPUT);
  pinMode(grn_pin_0, OUTPUT);
  pinMode(blu_pin_0, OUTPUT);

  pinMode(red_pin_1, OUTPUT);
  pinMode(grn_pin_1, OUTPUT);
  pinMode(blu_pin_1, OUTPUT);

  pinMode(red_pin_2, OUTPUT);
  pinMode(grn_pin_2, OUTPUT);
  pinMode(blu_pin_2, OUTPUT);

  inc_sw    = MomentarySwitch(inc_pin, &aw);
  dec_sw    = MomentarySwitch(dec_pin, &aw);
  enter_sw  = MomentarySwitch(enter_pin, &aw);

  frq_inc_btn = MomentarySwitch(frq_inc_btn_pin, &aw);
  red_inc_btn = MomentarySwitch(red_inc_btn_pin, &aw);
  grn_inc_btn = MomentarySwitch(grn_inc_btn_pin, &aw);
  blu_inc_btn = MomentarySwitch(blu_inc_btn_pin, &aw);
  frq_dec_btn = MomentarySwitch(frq_dec_btn_pin, &aw);
  red_dec_btn = MomentarySwitch(red_dec_btn_pin, &aw);
  grn_dec_btn = MomentarySwitch(grn_dec_btn_pin, &aw);
  blu_dec_btn = MomentarySwitch(blu_dec_btn_pin, &aw);

  //____________________________________________________________________

  Serial.begin(9600);
  display.led_segments.begin(LED_BACKPACK_ADDR);
  Wire.begin();

  //____________________________________________________________________

  cc0 = new ColorClock(&the_clock, cc0_period, ColorConst::rgb_);
  cc1 = new ColorClock(&the_clock, cc1_period, ColorConst::roygbiv_);
  cc2 = new ColorClock(&the_clock, cc2_period, ColorConst::roygbiv_);
  cc3 = new ColorClock(&the_clock, cc3_period, ColorConst::roygbiv_);

  // TODO make buttons a vector
  top_level = TopLevel(&the_clock
    , &display
    , inc_sw
    , dec_sw
    , enter_sw
    , &aw
    , frq_inc_btn
    , red_inc_btn
    , grn_inc_btn
    , blu_inc_btn
    , frq_dec_btn
    , red_dec_btn
    , grn_dec_btn
    , blu_dec_btn
  );

  top_level.register_color_clock(cc0, red_pin_0, grn_pin_0, blu_pin_0);
  top_level.register_color_clock(cc1, red_pin_1, grn_pin_1, blu_pin_1);
  top_level.register_color_clock(cc2, red_pin_2, grn_pin_2, blu_pin_2);
  top_level.register_color_clock(cc3, red_pin_3, grn_pin_3, blu_pin_3);
  top_level.set_participant_ctrl(cc0);

  the_clock.set_yr(START_YEAR);
  the_clock.set_month(START_MONTH);
}


//______________________________________________________________________
void loop()
{
  top_level.run();
}

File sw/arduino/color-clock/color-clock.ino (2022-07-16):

#include <Arduino.h>
#include <Wire.h>

#include <Adafruit_GFX.h>
#include "Adafruit_LEDBackpack.h"
#include <DS3231.h>

#include "alpha-display.hpp"
#include "classes.hpp"
#include "color-clock.hpp"
#include "debug.hpp"
#include "logic.hpp"
#include "time-calcs.hpp"

ColorClock the_first_colorclock;

byte set_hr    = 13;
byte set_min   = 54;
bool first_run = true;


//------------------------------------------------------------------------------
void setup(){
  Serial.begin(9600);
  the_first_colorclock.the_alpha_display.led_segments.begin(0x70);
  Wire.begin();

  // left off here - don't know why I can't see these
  // might want to move forward with a color clock object
  //initialize_color_selection(color_selection);
  //initialize_main_colors(main_colors);
}

//------------------------------------------------------------------------------
void loop(){

  // initialize clock
  if (first_run == true) {
    the_first_colorclock.the_rtc.setHour(set_hr);
    the_first_colorclock.the_rtc.setMinute(set_min);
    first_run = false;
  }

  Debug::print_time(the_first_colorclock.the_rtc);
  
  the_first_colorclock.update_display_time();

  delay(1000);
}

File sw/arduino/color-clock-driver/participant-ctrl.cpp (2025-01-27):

//______________________________________________________________________
//______________________________________________________________________
//      _   __   _   _ _   _   _   _         _
// |   |_| | _  | | | V | | | | / |_/ |_| | /
// |__ | | |__| |_| |   | |_| | \ |   | | | \_
//  _  _         _ ___  _       _ ___   _                        / /
// /  | | |\ |  \   |  | / | | /   |   \                        (^^)
// \_ |_| | \| _/   |  | \ |_| \_  |  _/                        (____)o
//______________________________________________________________________
//______________________________________________________________________
//
//----------------------------------------------------------------------
// Copyright 2024, Rebecca Rashkin
// -------------------------------
// This code may be copied, redistributed, transformed, or built upon in
// any format for educational, non-commercial purposes.
//
// Please give me appropriate credit should you choose to use this
// resource. Thank you :)
//----------------------------------------------------------------------
//
//______________________________________________________________________
// //\^.^/\\   //\^.^/\\   //\^.^/\\   //\^.^/\\   //\^.^/\\   //\^.^/\\
//______________________________________________________________________
//______________________________________________________________________
// Implementation for participant user control functions.
//______________________________________________________________________

#define DEFAULT_MOD_AMT 0x7F
#include <stdint.h>
#include "debug.hpp"
#include "participant-ctrl.hpp"

using Rgb = RgbColor::PriColor;

void ParticipantCtrl::run()
{
  bool inc_frq = frq_inc_btn_->is_short_press();
  bool dec_frq = frq_dec_btn_->is_short_press();
  bool inc_red = red_inc_btn_->is_short_press();
  bool dec_red = red_dec_btn_->is_short_press();
  bool inc_grn = grn_inc_btn_->is_short_press();
  bool dec_grn = grn_dec_btn_->is_short_press();
  bool inc_blu = blu_inc_btn_->is_short_press();
  bool dec_blu = blu_dec_btn_->is_short_press();

  if(
    inc_red  ||
    dec_red  ||
    inc_grn  ||
    dec_grn  ||
    inc_blu  ||
    dec_blu
  )
  {
    Debug::print_str_with_new_line("\n_________________________");
    Debug::print_str_with_new_line("BEFORE MOD");
    Debug::print_new_line();
    clock_->print();
    Debug::print_new_line();
  }

  //____________________________________________________________________
  // Frequency is multiplicative inverse of cycle time, i.e.
  // frequency increase = cycle time decrease
  // frequency decrease = cycle time increase
  //____________________________________________________________________
  if (dec_frq)
  {
    Serial.println("frq_dec pressed");
    clock_->mod_cycle_time(RgbColor::IncDec::INC);
  }

  if (inc_frq)
  {
    Serial.println("frq_inc pressed");
    clock_->mod_cycle_time(RgbColor::IncDec::DECREMENT);
  }

  if (dec_red)
  {
    Debug::print_str_with_new_line("\n_________________________");
    Serial.println("red_dec pressed");
    clock_->mod_color_selection(Rgb::RED, RgbColor::IncDec::DECREMENT);
  }

  if (inc_red)
  {
    Debug::print_str_with_new_line("\n_________________________");
    Serial.println("red_inc pressed");
    clock_->mod_color_selection(Rgb::RED, RgbColor::IncDec::INC);
  }

  if (dec_grn)
  {
    Debug::print_str_with_new_line("\n_________________________");
    Serial.println("grn_dec pressed");
    clock_->mod_color_selection(Rgb::GRN, RgbColor::IncDec::DECREMENT);
  }

  if (inc_grn)
  {
    Debug::print_str_with_new_line("\n_________________________");
    Serial.println("grn_inc pressed");
    clock_->mod_color_selection(Rgb::GRN, RgbColor::IncDec::INC);
  }

  if (dec_blu)
  {
    Debug::print_str_with_new_line("\n_________________________");
    Serial.println("blu_dec pressed");
    clock_->mod_color_selection(Rgb::BLU, RgbColor::IncDec::DECREMENT);
  }

  if (inc_blu)
  {
    Debug::print_str_with_new_line("\n_________________________");
    Serial.println("blu_inc pressed");
    clock_->mod_color_selection(Rgb::BLU, RgbColor::IncDec::INC);
  }

  if(
    inc_red  ||
    dec_red  ||
    inc_grn  ||
    dec_grn  ||
    inc_blu  ||
    dec_blu
  )
  {
    //Debug::print_str_with_new_line("\n_________________________");
    //Debug::print_str_with_new_line("AFTER MOD");
    //Debug::print_new_line();
    //Debug::print_str_with_new_line(
    //  (char*)("_________________________"));
    //Debug::print_str_with_new_line(
    //  (char*)(" Current Color Selection "));
    //Debug::print_str_with_new_line(
    //  (char*)("_________________________"));
    //Debug::print_color_array(clock_->crnt_color_selection_);
    //Debug::print_new_line();
  }
}

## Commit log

2020-07-01 fixed floating point error with negative number close to 0
    [color_clock.pde]
2020-08-12 added function to convert rgb to hsv, not showing correct conversion
    [color_clock.pde]
2020-08-12 fixed rgb - hsv conversion, added function for hsv to rgb, need to finish writing function
    [color_clock.pde]
2020-08-12 added print function for rgb color
2020-08-12 cleaned up color printing functions
2020-09-08 fixed rgb to hsv algorithm, added hsv to rgb algorithm, added comments
    [color_clock.pde]
2020-09-08 update time every millisecond
2020-09-12 fixed (?) millisecond calculation
    [color_clock.pde]
2022-04-24 displays current time, does not update
2022-05-10 arduino talks to both color clock and LED display
2022-05-14 incorporating code from processing into the arduino code base
2022-06-01 work in progress, doesn't compile
    [color-clock.ino]
2022-06-02 fixed compile errors, currently compiles
2022-06-10 trying to fix compile errors
    [color-clock.ino]
2022-06-14 added time calcs, currently compiles
2022-06-22 added stuff, currently compiles
2022-06-24 refactored, currently compiles
2022-06-27 added time stuff, currently compiles
2022-07-10 removed #ifdef DEBUG from print_time function
2022-07-10 fixed wrong variable in print_labeled_dec
    [debug.cpp, retry-color-clock.ino]
2022-07-11 currently compiles, working through initialize array functions, also think at the point to overwrite color clock files
2022-07-15 removed first attempt at clock - deleted broken code
    [color-clock.ino]
2024-02-04 added top-level schematic with versions
2024-03-07 Debounce test (#6)
    added code for momentary switch, updated docs
2024-03-23 Merged PR 2: Created time controller
    Created class for time controller that contains member variables for real-time clock, push buttons and LED segment display.
    Added images and blog post.
2024-04-27 Merged PR 4: Incorporated ColorClock into top level
    - Incorporated ColorClock objects into top level.
    - Added wrapper class for clock
    - Fixed interpolate function for HsvColor.
    - Added unit test for color classes.
    - Updated coding style.
    [color-clock-driver.ino, debug.cpp]
2024-05-14 Merged PR 5: Added examples to test time display and rtc module
    - Added time display and rtc module examples
    - Added blog post
    - Fixed `#if ARDUINO_BUILD` to `ifdef ARDUINO_BUILD`
2024-05-30 Merged PR 7: added error handling for time units out of range
    added error handling for time units out of range
    [color-clock-driver.ino]
2024-06-02 Merged PR 9: updated input pins for push buttons, redefined frequencies
    - Corrected bug where board freezes - can't use static class variables to define globals in .ino file
    - Updated input pins for push buttons, changed frequencies
    [color-clock-driver.ino]
2024-06-02 Merged PR 10: Increase time resolution to milliseconds
    - Added function to get the current millisecond in order to smooth out color transitions for small time periods.
    - Added macro file
    - Updated macro to be more descriptive on when to include the DS3231 functions.
2024-06-09 Merged PR 11: Added AutoCAD drawings
    - Added AutoCAD drawings for bread board and acrylic sheet.
    - Added script for installing relevant libraries from arduino-cli
    - Updated .gitignore
    [acrylic-sheet-rev.dwg, color-clock.dwg]
2024-06-24 Merged PR 13: Updated macros, changed byte to uint8, added examples
    - Modified RGB values in `RgbColor` to map instead of individual member variables
    - Broke out color-classes into two files, `rgb-color` and `hsv-color`
    - Updated build flags to allow for non-arduino unit testing
    - Changed usage of `byte` to `uint8_t`
    - Added examples for mux
    - Added images and videos
    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
    [DS3231_set.ino, DS3231_test.ino, color-clock-driver.ino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]
2024-06-29 Merged PR 14: Added IO expander, participant intfc base
    - Added flag to momentary-switch for option to use io expander
    - Add preliminary participant interface class
    - Added examples for io expander and participant interface
2024-07-04 Merged PR 15: Integrated participant control panel
    - Integrated participant control panel
    - Integrated Adafruit AW9523 I/O panel for buttons
    - Added color clock unit test
    - Fixed HSV color interpolation
    [color-clock-driver.ino, debug.cpp]
2024-07-20 Merged PR 16: Updated pins to match circuit
    - Updated pin assignments to match board
    - Inversed pwm output for testing
2024-07-27 Merged PR 17: Change time set state change criteria, added rgb-pwm-cycle
    - Changed catalyst for time set state change to accelerate response time
    - Added example that cycles through spectrum
    - Write seconds to display during idle
2024-07-29 Merged PR 18: Updated pins for timer set
    updated pins for timer set based on board layout
2024-08-09 Merged PR 19: Swapped order of ColorClock objects, added constants
    - Swapped order of ColorClock objects to match hardware
    - Swapped inc / dec time buttons
    - Added preprocessor constants
    [color-clock-driver.ino]
2024-08-21 Merged PR 22: Final software updates
    - Fixed participant control panel color clock
    - Fixed macros
    - Added define test example
    - Reorganized example
    [color-clock-driver.ino]
2024-11-28 Merged PR 24: Added drawings and reorganized images
    - Added slide deck for demo
    - Renamed autocad drawings
    - Reorganized images
    [acrylic-sheet-rev.dwg, box-divider-4.25in-v0__2024-08-04.stl, box-divider-4.2in-v1__2024-08-08.stl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]
2024-11-28 Merged PR 25: Added acad dwg for demo presentation
    added acad dwg for demo presentation
    [color-clock-presentation.dwg]
2025-02-02 Merged PR 27: Updated README
    Updated README with wiring diagram, link to code base, and links to documentation.
2025-02-10 Merged PR 28: Added Google Test
    - Add Google Test libraries and headers
    - Added placeholder test files for modules
    - Added unit tests for `get_time_as_fractional_offset` (currently failing 😭)
    - Added makefile to build unit tests
    - Added script to add `#define DEBUG_CPP` to `flux_macros.hpp`
2025-02-16 Merged PR 29: Added wire harness DOT diagram, added blog entry
    - Added DOT diagram for wire harness
    - Added blog entry for google test progress
